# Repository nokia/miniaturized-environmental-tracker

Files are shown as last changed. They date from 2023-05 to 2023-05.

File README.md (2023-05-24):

# Introduction 

 Miniaturized Environmental Tracker is a device developed by Data and Device Group of Nokia Bell Labs at Cambridge site during 2018-2020. The device is called Gecko (originally: gatekeeper) and both names are widely used in this repository.   
 The original and main developer of the firmware is our previous colleague Philip Derrick (https://github.com/phild68).

## Devices details

Gecko is a portable environmental sensing device. It contains temperature, air pressure, air quality, light, sound and IMU sensors. The device also has a solar panel for energy harvesting. We have manufactured hardware devices in two sizes, with different dimensions and battery sizes. 
1) Gecko, the normal size device, has a size of 55x25x15 mm with 500 mAh LiPo battery and  weight of about 24 grams. 

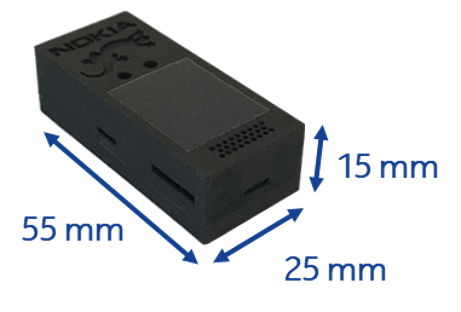
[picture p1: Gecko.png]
Gecko


2) Geckino, smaller size version, has a size of  40x25x15 mm with 150 mAh LiPo battery and weight of about 16 grams.    
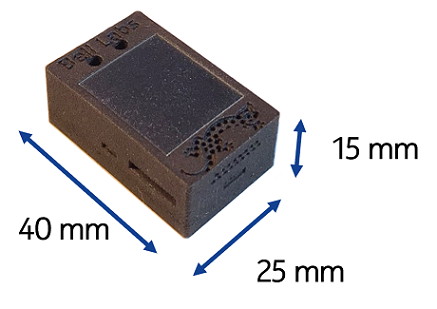
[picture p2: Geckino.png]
Geckino


### MCU and Sensors
* MCU is ARM-based Cortex M4-F 64MHz processor nRF52832 from Nordic Semiconductor.   
* Pressure and temperature sensor: LPS22HB from STMicroelectronics.  
* Gas Quality Sensor (Volatile Organic Compounds): BME680 from Bosch Sensortec. It can measure temperature, pressure and humidity as well.  
* Colour/Light Sensor: BH1745NUC from Rohm Semiconductor.  
* Digital microphone: MP34DT05 from STMicroelectronics.  
* Motion Sensor (6-axis, Accelerometer and Gyroscope): BMI160 from Bosch Sensortec.  

## Data parsing
Gecko's data can be saved on SD card or real time streamed over BLE according to application scenarios. All sensor's data saved in SD cards is in binary format with filename DLOG\_\*.BIN. The BIN file data can be procesed by python scripts for human and machine reading. 

## Firmware and programming instructions

The firmware for Gecko was developed in Segger Embedded Studio with Nordic Semiconductor nRF5 SDK 15.3.0 with softdevice version s132. 
Segger Embedded Studio can be downloaded: https://www.segger.com/products/development-tools/embedded-studio/

nRF5 SDK 15.3.0 can be downloaded: https://www.nordicsemi.com/Products/Development-software/nRF5-SDK/Download#infotabs

JLink device hardare, its drive (https://www.segger.com/downloads/jlink/) and nRF Command Line Tools are also required for compiling and uploading the firmware to device. 

## How to start 
Download and Install Segger Embedded Studio and get a license for Nordic MCU as needed. Version of SDK used is:   
* nRF5 SDK 15.3.0    

Download above nRF5 SDK 15.3.0 and unzip the whole package of nRF5_SDK_15.3.0_59ac345 in a working directory and copy gecko-fw folder in this repository into it. The Segger project file for gecko-fw can be loaded from:  
`gecko-fw/ble_peripheral/ble_app_gatekeeper/gecko/s132/ses/ble_app_gecko_s132.emProject`

### Modifications to nRF5 SDK 15.3.0 files
The following code modifications may be required for compiling in current version of Segger Embedded Studio 6.34: 
1. 	 components/libraries/uart/regart.c 

	Line 101 change: 
	`#if defined(__SES_VERSION) && (__SES_VERSION >= 34000)` to 
	`#if defined(__SES_VERSION) && (__SES_VERSION >= 34000) && !defined(__SEGGER_RTL_VERSION)`
2.   external/fatfs/src/ffconf.g

	Line 101 change to the following to enable long filename support:
	`#define	_USE_LFN	2`
3.   components/libraries/bsp/bsp_config.h

	Line 89 and 90: 
	`#define ADVERTISING_LED_ON_INTERVAL            50 //200`
	`#define ADVERTISING_LED_OFF_INTERVAL           9950 //1800`
	This is to make the LED advertising less frequently. 
4.   You may also need to change the following file: 	external/segger_rtt/SEGGER_RTT_Syscalls_SES.c

  Add `#if !defined(__SEGGER_RTL_VERSION)` at line 72 and `#endif` at around line 262.
   
If there are more errors during compiling, you may want to switch Segger Embedded Studio to early version published during 2019, for instance V5.40.
### Other compiler
The project can also be complied with armgcc. the Makefile is located at: gecko-fw/ble_peripheral/ble_app_gatekeeper/gecko/s132/armgcc 

### Hardware programming interface
First time programming of Gecko need to go through SWD interface embedded with micro-USB plug. SWD pin configuration can be found in the hardware schematic files. A customized interface connection need to be made to programmer (JLink or others). 

### Other related instructions 
 Other useful documents and related instructions:

 * gecko-fw/README.md
 * gecko-fw/ble_peripheral/ble_app_gatekeeper/DFU_README.md  
 
 ## Other files in this repository
 
 * gecko-hw  
 Gecko PCB hardware design files for production.
 
 * gecko_ble_gateway  
 Raspberry Pi gateway used to collect Gecko data over BLE in real time, parsing data and forward  data in json format to remote server. 
 
 * gecko-case  
 Case designs for both versions of the device: Gecko and Geckino.

 * data_parsing_scripts  
 For processing binary files in \*.BIN format saved on SD card to human readable format. Similar script is also used in gecko_ble_gateway files.

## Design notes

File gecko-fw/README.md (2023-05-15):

# Gecko Sensor Electronics Firmware

This project develops firmware for Gecko environmental sensor. 

This database (gecko-fw folder) should be cloned into the top level of the nRF5 SDK. The version used for development is nRF5\_SDK\_15.3.0\_59ac345. This can be obtained from the Nordic Website ([https://www.nordicsemi.com/Software-and-Tools/Software/nRF5-SDK/Download#infotabs]())

In this case, place gecko-fw folder under nRF5_SDK_15.3.0_59ac345.

All code has been developed using SES and aslo tested with armgcc. 

### To Make a DFU firmware image
1) Build the firmware in Segger Studio.  
2) go to /ble_peripheral/ble_app_gatekeeper.  
3) On a PC in command line run: "sh generateSoftDeviceAndBootloaderHex.sh".  
4) Go to Segger Studio and Upload Image to device.   

### To Make a .zip file
1) Build the firmware in Segger Studio  
2) go to /ble_peripheral/ble_app_gatekeeper  
3) On a PC in command line run: "sh make_zip_file.sh"  
4) Transfer .zip to phone and use nRF Connect 

### Use of Makefile
Makefile under the folder /ble_peripheral/ble_app_gatekeeper is fully working now. One thing need to be done is to add Segger Embedded Studio bin folder to path of the shell you are using. One Mac the following can be added to the end of .bash_prifile (or .zshrc if you are ing zsh), with your version of Segger Embedded Studio. 

```bash
# Segger Embedded Studio  
export SEGGER_VERSION=4.40  
export PATH="$PATH:/Applications/SEGGER Embedded Studio for ARM ${SEGGER_VERSION}/bin"

```

#### Then make has the follow targes to use:  

     all                                    :  Prepare hex and zip files, not including program and upload2cloud  
     micro-ecc                              :  Obtain and make the micro-ecc library. Only needs to be done once.  
     bootloader                             :  Compile secure bootloader image
     bootloader_Settings.hex                :  Generate bootloader settings for current application.  
     bootloaderWithSettings.hex             :  Combine bootloader with bootloader settings.  
     merged_SD_Bootloader.hex               :  Combine bootloader with bootloader settings and SoftDevice.  
     merged_SD_Bootloader_Application.hex   :  Combine bootloader with bootloader settings, SoftDevice, and Application.  
     app_dfu_package.zip                    :  Generate the package for DFU update
     program                                :  Program the Initial Image to nrf52 device. 
     upload2cloud                           :  Upload the initial Image to iClould on Mac computer.  
     clean                                  :  Clean volatile stuff.  
     clean-all                              :  Clean Everything including micro-ecc

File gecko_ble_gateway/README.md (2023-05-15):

# Gecko Gateway Apps

|  Directory | Gateway Version  | 
|---|---|
|  gw.python | Raspberry Pi version  |

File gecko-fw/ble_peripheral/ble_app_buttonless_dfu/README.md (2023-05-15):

# Buttonless DFU for Gecko

##Reference
[https://devzone.nordicsemi.com/nordic/nordic-blog/b/blog/posts/getting-started-with-nordics-secure-dfu-bootloader
]()

Note: The above tutorial instructs to flash the softdevice first, and then the bootloader. THIS DOES NOT WORK as the bootloader overwrited the softdevice. The correct way to do this is to use mergehex to merge the two hex files together. This is part of the nRF Command Line Tools (as is nrfjprog). 

There is also a step-by-step tutorial (which uses mergehex) based on the above at 
[https://github.com/gamnes/nRF52832-buttonless-dfu-development-tutorial]()

## Steps

Step A. Generate keys

Step B. Build the bootloader and merge with the softdevice.

Step C. Generate DFU .zip packet

Step D. Test DFU

Step E. Update new application firmware (Optional)

##Notes
Generated Keys are in dfu/gecko\_public\_key.c and dfu/gecko\_private.key in the workspace.

Bootloader is dfu/secure\_bootloader

ble\_peripheral/ble\_app\_buttonless_dfu is the current starter example. This is where the zip file is located. 

## Step A. Generate Keys
In ble\_peripheral/ble\_app\_buttonless_dfu run the following nrfjprog command to generate the private key

`nrfutil.exe keys generate private.key
`

Generate the public key based on the private key

`nrfutil keys display --key pk --format code private.key --out_file public_key.c
`

This step has already been done and the keys are included in this repository: 

		dfu/gecko_public_key.c
		dfu/gecko_private.key 

## Step B. Build the BootLoader

This needs to be rebuilt using the private key generated above. 

Scripts have been provided to do this. 

1. Install micro\_ecc in the nRF5-SDK (01\_uECC\_build.sh)
2. Build the bootloader and merge with the softdevice (02\_Bootloader\_build.sh)
3. Build the DFU image from the required application (03\_DFU\_build.sh)
4.

## Step C. Generate the DFU .zip Packet

Build the new version of the application and then build the signed package.

For an example go to ble\_peripheral/ble\_app\_buttonless\_dfu and run the 03\_DFU\_build.sh script.

## Step D. Test DFU
Program the bootloader with 04\_DFU\_Program.sh

Use over the air update to program the application. This requires nRFConnect and does not work on Linux or OSX.

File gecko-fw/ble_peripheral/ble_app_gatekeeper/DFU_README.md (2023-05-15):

# Gecko Device Firmware Update (DFU) Instruction

## Step 1 - Keys

Keys have already been generated and are in dfu/gecko\_public\_key.c and dfu/gecko\_private.key in the workspace. Replacement keys can be generated with the following commands: -

`nrfutil keys generate private.key`

`nrfutil keys display --key pk --format code private.key --out_file dfu_public_key.c`

## Step 2 - Install Micro-ECC

Go to the SDK Root directory and enter external/micro-ecc. Run build_all.sh or build_all.exe. On UNIX based systems (including OS-X) it may be necessary to run dos2unix on build_all.sh first.

## Step 3 - Build Bootloader

Bootloader is in dfu/secure\_bootloader folder. To build the bootloader go to that directory and run make. Use the argument DEBUG=1 for the debug build.

## Step 4 - Compile the Application
Compile the Application in Segger Embedded Studio using 

`gecko/s132/ses/ble\_app\_gecko\_s132.emProject`

The application hex file should be located under 

`gecko/s132/ses/Output/Debug/Exe/ble\_app\_gecko\_s132.hex`

## Step 5 - Modify Bootloader and combine images.
The bootloader then needs to be modified with the details of the Application executable. For this, the generateSoftDeviceAndBootloaderHex.sh can be used. This generates the correct bootloader settings for the Application, and merges this resultant hex with the bootloader hex, and then with the softdevice hex producing a single hex file that can be loaded by Segger Embedded Studio. It also creates the combined Application, Bootloader and Softdevice for programming with nrfjprog. 

SES calls a script from the <project>/s132/ses directory which calls the generateSoftDeviceAndBootloaderHex.sh after Linking and before Loading.

## Makefile Option
Ultimately these steps should be wrapped up in a makefile but currently this is not fully working.

## Application DFU Package
To generate the package to transmit over the DFU protocol run 

`make app_dfu_package.zip`

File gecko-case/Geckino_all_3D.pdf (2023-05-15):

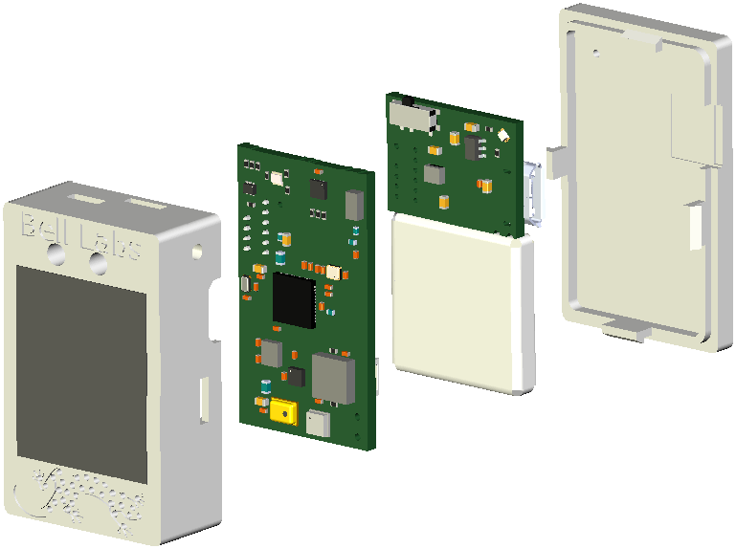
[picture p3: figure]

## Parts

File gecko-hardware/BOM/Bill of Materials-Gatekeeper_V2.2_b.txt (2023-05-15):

Designator,Name,Quantity,Description,Manufacturer 1,Manufacturer Part Number 1,Manufacturer Lifecycle 1,Supplier 1,Supplier Part Number 1,Supplier Unit Price 1,Supplier Subtotal 1
,,,,,,,,,,
AT1,2450AT18B100,1,2.45 GHz chip antenna,Johanson,2450AT18A100E,Volume Production,Arrow,2450AT18A100E,0.47459,0.47459
"C1, C12",4.7uF,2,"Capacitor, 0603, X5R, ±10% ",KEMET,C0603C475K9PACTU,Volume Production,Digi-Key,399-3482-6-ND,0.13424,0.26849
C2,10nF,1,"Capacitor, 0402, X7R, ±5%",Yageo,CC0402JRX7R9BB103,Volume Production,Arrow,CC0402JRX7R9BB103,0.07502,0.07502
C3,47uF,1,"Chip Capacitor, 47 uF, +/- 20%, 10 V, -55 to 85 degC, 0805 (2012 Metric), RoHS, Tape and Reel",TDK,C2012X5R1A476M125AC,Volume Production,Mouser,810-C2012X5R1A476M,0.83705,0.83705
"C4, C11, C13, C17, C24, C25, C26, C27, C28, C29, C30, C32, C35, C37",100nF,14,"Capacitor, 0402, X7R, ±10%",Wurth Electronics,885012205037,Volume Production,Mouser,710-885012205037,0.01579,0.22111
"C5, C6, C14, C31",1.0uF,4,"Capacitor, 0603, X7R, ±10% ",Taiyo Yuden,JMK107B7105KA-T,Volume Production,Mouser,963-JMK107B7105KA-T,0.07897,0.31587
"C7, C36",10uF,2,"Capacitor, 0603, X5R, ±10%",TDK,C1608X5R1A106K080AC,Volume Production,Future Electronics,C1608X5R1A106K080AC-CUTT,0.14846,0.29692
C8,22uF,1,"Capacitor, 0603, X5R, ±20%",TDK,C1608X5R1A226M080AC,Volume Production,Future Electronics,C1608X5R1A226M080AC-CUTT,0.12793,0.12793
"C9, C10, C15, C16, C19, C20",12pF,6,"Capacitor, 0402, NP0, ±2%",Murata,GJM1555C1H120GB01D,Volume Production,Digi-Key,490-8078-6-ND,0.21321,1.28
C18,0.8pF,1,"Capacitor, NP0, ±5%",Murata,GJM1555C1HR80WB01D,Volume Production,Arrow,GJM1555C1HR80WB01D,0.22498,0.22498
C21,100pF,1,"Capacitor, 0402, NP0, ±5%",Murata,GRM0225C1E101JA02L,Volume Production,Arrow,GRM0225C1E101JA02L,0.07502,0.07502
C23,2.2pF,1,"Capacitor, 0402, NP0, ±0.1pF",Murata,GJM1555C1H2R2BB01D,Volume Production,Arrow,GJM1555C1H2R2BB01D,0.12753,0.12753
"C33, C34",270pF,2,"Capacitor, 0402, NP0, ±2%",KEMET,C0402C271G5GACTU,Volume Production,Mouser,80-C0402C271G5G,0.82126,1.64
FB1,600R/0.5A,1,"Ferrite Bead, 0603, 600 Ohm @ 100MHz, 500mA, 380 mOhm Max",Murata,BLM18AG601SN1D,Volume Production,Future Electronics,BLM18AG601SN1D-CUTT,0.02993,0.02993
J1,FPC 0.5mm RA SMD,1,"0.5mm FPC, 5P,Right Angle SMT,Double Contact,H=1.2mm,White, Tin plated",Molex,51281-0594,Volume Production,Arrow,51281-0594,0.33924,0.33924
L1,LPS4018-223MRB,1,"Shielded Power Inductor, 22 uH, +/- 20%, 360 mOhm, -40 to 85 degC, 2-Pin SMD, RoHS, Tape and Reel",Coilcraft,LPS4018-223MRB,Volume Production,Mouser,994-LPS4018-223MRB,0.90023,0.90023
L2,15nH,1,"Inductor, 0402, 320mA, ±5%",Taiyo Yuden,HK100515NJ-T,Volume Production,Future Electronics,HK100515NJ-T-CUTT,0.01571,0.01571
L3,10uH,1,"Inductor, 0603, 80mA, ±10%",Taiyo Yuden,LBMF1608T100K,Volume Production,,,,
"L4, L6",3.9nH,2,"Inductor, 170mA, ±0.1nH",Murata,LQP15MN3N9B02D,Volume Production,Digi-Key,490-1131-6-ND,0.15004,0.30008
LED1,Red,1,"SMD mono-color Chip LED, WL-SMCW, Red",Wurth Electronics,150060RS75000,Volume Production,Digi-Key,732-4978-1-ND,0.11055,0.11055
LED2,LED RGB,1,RGB LED 1.60 mm x 1.60 mm SMD,Vishay Lite-On,LTST-C19HE1WT,Volume Production,Future Electronics,LTST-C19HE1WT-CUTT,0.17373,0.17373
P3,MicroUSB-B,1,MicroUSB-B-SMT,Amphenol FCI,10118193-0001LF,Volume Production,Allied Electronics,70236827,0.26849,0.26849
Q1,DMC2400UV,1,"Dual N & P Ch MOFET, 1.03A/0.7A, 480mOhm, 450mW",Diodes,DMC2400UV-7,Volume Production,Digi-Key,DMC2400UV-7DIDKR-ND,0.39484,0.39484
"R1, R9",4.42M,2,"Resistor, 0402, ±1%, 0.063W",Yageo,RC0402FR-074M42L,Volume Production,Mouser,603-RC0402FR-074M42L,0.00948,0.09476
R2,10M,1,"Resistor, 0402, ±1%, 0.063W",Yageo,RC0402FR-0710ML,Volume Production,Future Electronics,RC0402FR-0710ML-CUTT,0.00229,0.00229
"R2b, R8",5.62M,2,"Resistor, 0402, ±1%, 0.063W",Yageo,RC0402FR-075M62L,Volume Production,Mouser,603-RC0402FR-075M62L,0.00948,0.09476
R3,4.32k,1,"Resistor, 0402, ±1%, 0.063W",Vishay,CRCW04024K32FKED,Volume Production,Farnell,1151240,0.0114,0.0114
R4,470R,1,"Resistor, ±1%, 0.063W",Vishay,CRCW0402470RFKED,Volume Production,Digi-Key,541-470LDKR-ND,0.07897,0.07897
R5,XH10k,1,THERMISTOR 10K OHM NTC 0402 SMD,Murata,NCP15XH103F03RC,Volume Production,Future Electronics,NCP15XH103F03RC-CUTT,0.06594,0.06594
"R6, R11",6.04M,2,"Resistor, 0402, ±1%, 0.063W",Yageo,RC0402FR-076M04L,Volume Production,Mouser,603-RC0402FR-076M04L,0.00948,0.09476
R7,3.83M,1,"Resistor, 0402, ±1%, 0.063W",Panasonic,ERJ-2RKF3831X,Volume Production,Arrow,ERJ-2RKF3831X,0.07502,0.07502
R10,3.32M,1,"Resistor, 0402, ±1%, 0.063W",Yageo,RC0402FR-073M32L,Volume Production,Arrow,RC0402FR-073M32L,0.07502,0.07502
R12,536k,1,"Resistor, 0402, ±1%, 0.063W",Panasonic,ERJ-2RKF5360X,Volume Production,Arrow,ERJ-2RKF5360X,0.00411,0.00411
"R15, R22, R26, R27",10k,4,"Resistor, 0402, ±1%, 0.063W",Panasonic,ERJ2RKF1002X,Volume Production,Allied Electronics,70265404,0.00948,0.0379
R16,100R,1,"Resistor, 0402, ±1%, 0.063W",Vishay Dale,CRCW0402100RFKED,Volume Production,Future Electronics,CRCW0402100RFKED-CUTT,0.0064,0.0064
"R17, R18",39R,2,"Resistor, 0402, ±1%, 0.063W",Vishay,CRCW040239R0FKED,Volume Production,Future Electronics,CRCW040239R0FKED-CUTT,0.00576,0.01153
"R19, R24, R25",4k7,3,"Resistor, 0402, ±1%, 0.063W",Vishay,CRCW04024K70FKED,Volume Production,Future Electronics,CRCW04024K70FKED-CUTT,0.0135,0.04051
"R20, R21",1M0,2,"Resistor, ±1%, 0.063W",Vishay,CRCW04021M00FKED,Volume Production,Future Electronics,CRCW04021M00FKED-CUTT,0.00268,0.00537
R23,21k5,1,"Resistor, ±1%, 0.063W",Vishay,CRCW040221K5FKED,Volume Production,Mouser,71-CRCW0402-21.5K-E3,0.07897,0.07897
SD1,DM3D-SF,1,"Micro SD Card Connector, Push-Pull, Top Board Mounting, 125 V, 0.5 A, -25 to 85 degC, 8-Pin SMD, RoHS, Tape and Reel",Hirose,DM3D-SF,Volume Production,Future Electronics,DM3D-SF-CUTT,1,1
SW1,PCM12SMTR,1,"Ultraminiature Slide Switch, SPDT, 0.3 A, 6 V, -20 to 85 degC, 3-Pin SMD, RoHS, Tape and Reel",ITT C&K,PCM12SMTR,Volume Production,Allied Electronics,70417448,0.46433,0.46433
SW2,USLPT3026BL1TR,1,"Low-Profile Tactile Switch, SPST, 50 mA, 12 VDC, -40 to 85 degC, 4-Pin SMD, RoHS, Tape and Reel",TE Connectivity,USLPT3026BL1TR,,Farnell,2990969,0.475,2.38
U1,BQ25504RGTT,1,"Ultra Low Power Boost Converter with Battery Management for Energy Harvester App, 0.13 V, -40 to 85 degC, 16-pin QFN (RGT), Green (RoHS & no Sb/Br)",Texas Instruments,BQ25504RGTT,Volume Production,Newark,76T8906,1.93,1.93
U2,BQ21040DBVR,1,0.8A Single Input Single-Cell Li-Ion and Li-Pol Battery Charger,Texas Instruments,BQ21040DBVR,,Mouser,595-BQ21040DBVR,0.86864,0.86864
U3,XCL210C33,1,3.3V 200mA Inductor Built-in Step-Down “micro DC/DC” Converter,Torex,XCL210C331GR-G,Volume Production,Digi-Key,893-1255-6-ND,2.2,2.2
U4,nRF52832-QFAAB0,1,"Multi-protocol Bluetooth Low Energy, ANT and 2.4GHz proprietary system-on-chip",Nordic Semiconductor,NRF52832-QFAA-R,Volume Production,Arrow,NRF52832-QFAA-R,4.24,4.24
U5,BMI160,1,"BMI160, IMUs - Inertial Measurement Units 6-Axis 950uA",Bosch,BMI160,,Future Electronics,BMI160-CUTT,3.5,3.5
U6,SST26VF032-80-5I-S2AE,1,"32 Mbit Serial Quad I/O (SQI) Flash Memory, 2.7 to 3.6 V, 80 MHz, -40 to 85 degC, 8-pin SOIC (S2A8), Tube",Microchip,SST26VF032-80-5I-S2AE,Volume Production,Arrow,SST26VF032-80-5I-S2AE,2.16,2.16
U7,LPS22HB,1,MEMS nano pressure sensor: 260-1260 hPa absolute digital output barometer,STMicroelectronics,LPS22HBTR,Volume Production,Arrow,LPS22HBTR,1.94,1.94
U8,BME680,1,"Combined Humidity and Pressure Sensor, 1.71 to 3.6 V, -40 to 85 degC, 8-Pin SMD, RoHS, Tape and Reel",Bosch Sensortec,BME680,,Arrow,BME680,9.96,9.96
U9,MP34DT05,1,MEMS audio sensor omnidirectional digital microphone,STMicroelectronics,MP34DT05TR-A,,Future Electronics,MP34DT05TR-A-CUTT,0.75019,0.75019
U10,BH1745NUC,1,Digital 16bit Serial Output Type Color Sensor IC,Rohm,BH1745NUC-E2,Volume Production,Farnell,2663354,1.2,1.2
U11,NX3DV2567,1,Low-ohmic four-pole double-throw analog switch,NXP Semiconductors,"NX3DV2567GU,115",Volume Production,Arrow,"NX3DV2567GU,115",0.437,0.437
X1,32.768kHz,1,"XTAL SMD 2012, 32.768kHz, 9pF, ±20ppm",Abracon,ABS06-32.768KHZ-9-1-T,Volume Production,Future Electronics,ABS06-32.768KHZ-9-1-T-CUTT,0.42247,0.42247
X2,32MHz,1,"XTAL SMD 2016, 32MHz, Cl=8pF, Tot: ±40ppm",Kyocera AVX,CX2016DB32000D0WZRC1,Volume Production,Arrow,CX2016DB32000D0WZRC1,0.55948,0.55948

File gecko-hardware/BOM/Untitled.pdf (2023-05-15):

PatchKeeper_V1.0

Designator | Comment | Quantity | Footprint | Description
C1, C2 | GJM1555C1H120GB01D | 2 | CAPC0402(1005)60_L | Multilayer Ceramic Capacitors MLCC - SMD/SMT 0402 12pF 50Volts C0G 2%
C13, C14 | CAP 1uF 16V 0402(1005) | 2 | CAPC0402(1005)60_L | CAP 1uF 16V ±10% 0402 (1005 Metric) Thickness 0.6mm SMD
C15, C17 | GRM155R71E473KA88D | 2 | CAPC0402(1005)60_L | Chip Capacitor, 47 nF, +/- 10%, 25 V, -55 to 125 degC, 0402 (1005 Metric), RoHS, Tape and Reel
C16 | 10 uF | 1 | CAPC0603(1608)100_L | Capacitor, 0603, X7R, ±10%
C19 | 1.5nF 25V 0402(1005) | 1 | CAPC0402(1005)60_L | CAP 1.5nF 25V ±5% 0402 (1005 Metric) Thickness 0.6mm SMD
C20, C21 | GRM1557U1A302JA01D | 2 | CAPC0402(1005)60_L | 0402, 3000 pF, 10V, U2J, 5%, -55C - 125 C
C22, C23, C24, C25 | GRM155R71H222KA01D | 4 | CAPC0402(1005)60_L | Chip Capacitor, 2.2 nF, +/- 10%, 50 V, -55 to 125 degC, 0402 (1005 Metric), RoHS, Tape and Reel
C3 | 4.7uF | 1 | CAPC1608X06L | CAP 4.7uF 10V ±20% 0603 (1608 Metric) Thickness 0.55mm SMD
C34, C39, C44, C49 | CAP 100nF 16V 0603(1608) | 4 | CAPC0603(1608)100_L | CAP 100nF 16V ±5% 0603 (1608 Metric) Thickness 1mm SMD
C35, C40, C45, C50 | CAP 510pF 50V 0603(1608) | 4 | CAPC0603(1608)100_L | CAP 510pF 50V ±5% 0603 (1608 Metric) Thickness 1mm SMD
C4 | 10 uF | 1 | CAPC1608X06L | Capacitor, 0603, X7R, ±10%
C5, C10, C12, C18, C26, C27, C28, C29, C30, C32, C33, C37, C38, C42, C43, C47, C48 | CAP 100nF 16V 0402(1005) | 17 | CAPC0402(1005)60_L | CAP 100nF 16V ±10% 0402 (1005 Metric) Thickness 0.6mm SMD, CAP 100nF 16V ±20% 0402 (1005 Metric) Thickness 0.6mm SMD
C6 | CAP 4.7uF 10V 0603(1608) | 1 | CAPC1608X06L | CAP 4.7uF 10V ±20% 0603 (1608 Metric) Thickness 0.55mm SMD
C7 | CAP 4.7uF 16V 0805(2012) | 1 | CAPC0805(2012)155_L | CAP 4.7uF 16V ±10% 0805 (2012 Metric) Thickness 1.55mm SMD
C8 | CAP 10uF 16V 1206(3216) | 1 | CAPC1206(3216)130_L | CAP 10uF 16V ±20% 1206 (3216 Metric) Thickness 1.3mm SMD
C9, C11, C31, C36, C41, C46, C51 | CAP 1uF 25V 0603(1608) | 7 | CAPC0603(1608)100_L | CAP 1uF 25V ±10% 0603 (1608 Metric) Thickness 1mm SMD
FB1 | 600R/0.5A | 1 | INDC1608X06L | Ferrite Bead, 0603, 600 Ohm @ 100MHz, 500mA, 380 mOhm Max
JUM | N. M. | 1 | JUMPER 0603 CON | Jumper with one side connected, the other side can be connected with 0603 0 ohm.
L1 | DFE252012F-100M=P2 | 1 | INDC2520X120N | Fixed Inductors 10uH 480mOhms 1.4A 2.5x2.0mm 20%
LED | APT1608SRCPRV | 1 | LED_0603 | LED Super Bright Red, 75 mW, 5 V, -40 to 85 degC, 2-Pin SMD, RoHS, Tape and Reel
P2 | Pin List 1x2 | 1 | LIST_1X2-NC_SMALL | Pin List 1x2, 2.54mm (100mil)
Q1 | DMC2400UV | 1 | SOTFL50P162X60-6N | Dual N & P Ch MOFET, 1.03A/0.7A, 480mOhm, 450mW
R1 | 470R 1% 0603(1608) | 1 | RESC0603(1608)_L | 470R 0.1W 1% 0603 (1608 Metric) SMD
R10 | ERJ-2GE0R00X | 1 | RESC1005X40X25LL05T05 | Chip Resistor, 0 Ohm, +/- 5%, 100 mW, -55 to 155 degC, 0402 (1005 Metric), RoHS, Tape and Reel
R11 | 1M 1% 0402(1005) | 1 | RESC1005X40X25LL05T05 | 1M 0.063W 1% 0402 (1005 Metric) SMD
R13, R14 | 40K2 1% 0402(1005) | 2 | RESC1005X40X25LL05T05 | 40K2 0.063W 1% 0402 (1005 Metric) SMD
R15, R16 | 51K 5% 0402(1005) | 2 | RESC1005X40X25LL05T05 | 51K 0.063W 5% 0402 (1005 Metric) SMD
R17, R18, R19, R20 | 10M 1% 0402(1005) | 4 | RESC1005X40X25LL05T05 | 10M 0.063W 1% 0402 (1005 Metric) SMD
R2 | RMCF0603FT10K0 | 1 | RESC0603(1608)_L | Chip Resistor, 10 KOhm, +/- 1%, 0.1 W, -55 to 155 degC, 0603 (1608 Metric), RoHS, Tape and Reel
R21 | 100R 1% 0402(1005) | 1 | RESC0402(1005)_L | 100R 0.063W 1% 0402 (1005 Metric) SMD
R22, R23 | 39R2 1% 0402(1005) | 2 | RESC0402(1005)_L | 39R2 0.063W 1% 0402 (1005 Metric) SMD
R24, R31, R37, R44 | 1K 1% 0603(1608) | 4 | RESC0603(1608)_L | 1K 0.1W 1% 0603 (1608 Metric) SMD
R25 | 2K74 1% 0603(1608) | 1 | RESC0603(1608)_L | 2K74 0.1W 1% 0603 (1608 Metric) SMD
R26, R27 | 27K4 1% 0603(1608) | 2 | RESC0603(1608)_L | 27K4 0.1W 1% 0603 (1608 Metric) SMD
R28 | 80K6 1% 0603(1608) | 1 | RESC0603(1608)_L | 80K6 0.1W 1% 0603 (1608 Metric) SMD
R29 | 200K, 1% 0603 | 1 | RESC0603(1608)_L | 200K 0.1W 1% 0603 (1608 Metric) SMD
R3, R4 | 1M 1% 0402(1005) | 2 | RESC0402(1005)_L | 1M 0.063W 1% 0402 (1005 Metric) SMD
R30, R36, R43, R50 | 100R 1% 0603(1608) | 4 | RESC0603(1608)_L | 100R 0.1W 1% 0603 (1608 Metric) SMD
R32, R33, R34, R35, R41, R42, R48, R49 | 200K 1% 0603(1608) | 8 | RESC0603(1608)_L | 200K 0.1W 1% 0603 (1608 Metric) SMD
R38, R45 | 1K02 1% 0603(1608) | 2 | RESC0603(1608)_L | 1K02 0.1W 1% 0603 (1608 Metric) SMD
R39, R40, R46, R47 | 10K 1% 0603(1608) | 4 | RESC0603(1608)_L | 10K 0.1W 1% 0603 (1608 Metric) SMD
R5, R51 | 10K 1% 0402(1005) | 2 | RESC0402(1005)_L | 10K 0.063W 1% 0402 (1005 Metric) SMD
R6 | 21K5 1% 0402(1005) | 1 | RESC0402(1005)_L | 21K5 0.063W 1% 0402 (1005 Metric) SMD
R7, R8 | 10K 1% 0402(1005) | 2 | RESC1005X40X25LL05T05 | 10K 0.063W 1% 0402 (1005 Metric) SMD
R9, R12 | 100K 1% 0402(1005) | 2 | RESC1005X40X25LL05T05 | 100K 0.063W 1% 0402 (1005 Metric) SMD
RGB | LED RGB | 1 | LED_RGB_0606 | RGB LED 1.60 mm x 1.60 mm SMD
RST | =Value | 1 | TP_SMD_Ø1.2MM | SMD testpad of various size
SD | DM3AT-SF-PEJM5 | 1 | DM3AT-SF-PEJM5 | Connector
SW1 | | 1 | SWITCH_091029001 | SPDT slide Switch, TH
T2 | Pin List 1x2 | 1 | LIST_1X2-1.27 | Pin List 1x2, 2.54mm (100mil)
TR1 | TC42X-2-204E | 1 | TC42X2103E | Trimmer Resistors - SMD 200K 2mm SMD Single Turn
U1 | BT840 | 1 | XCVR_BT840 | Bluetooth LE Module, Nordic nRF52840 SoC, Range 180 meters
U2 | MCP73831T-2ACI/OT | 1 | SOT-23-OT5_L | Miniature Single-Cell, Fully Integrated Li-Ion, Li-Polymer Charge Management Controller, 4.2V, 5-Pin SOT-23, Industrial Temperature, Tape and Reel
U3 | LM3670MF-3.3/NOPB | 1 | DBV0005A_N | Miniature Step-Down DC-DC Converter for Ultra Low Voltage Circuits, 5-pin SOT-23, Pb-Free
U4 | ADS1292RIPBS | 1 | TI-PBS32_L | 2-Channel, 24-Bit ADC with Integrated Respiration Impedance and ECG Front End, -40 to 85 degC, 32-pin QFP (PBS32), Green (RoHS & no Sb/Br)
U5 | BMI160 | 1 | BMI160-LGA14 | BMI160
U6 | MP34DB02 | 1 | RHLGA-4 (3X4X1MM) | MEMS audio sensor omnidirectional digital microphone
U7, U8, U9, U10 | INA338AIDGSTG4 | 4 | TI-DGS10_L | Wide-Temperature, Precision Instrumentation Amplifier with Shutdown, -40 to 125 degC, 10-pin SOP (DGS10), Green (RoHS & no Sb/Br)
USB | MicroUSB-B | 1 | USB-MICRO-B-RA-SMD-PIP | MicroUSB-B-SMT
VR1, VR2, VR3, VR4 | LM4050AEM3-2.0 | 4 | DBZ0003A_L | Precision Micropower Shunt Voltage Reference, 3-pin SOT-23
X1 | 32.768kHz | 1 | XTAL_2012 | XTAL SMD 2012, 32.768kHz, 9pF, ±20ppm

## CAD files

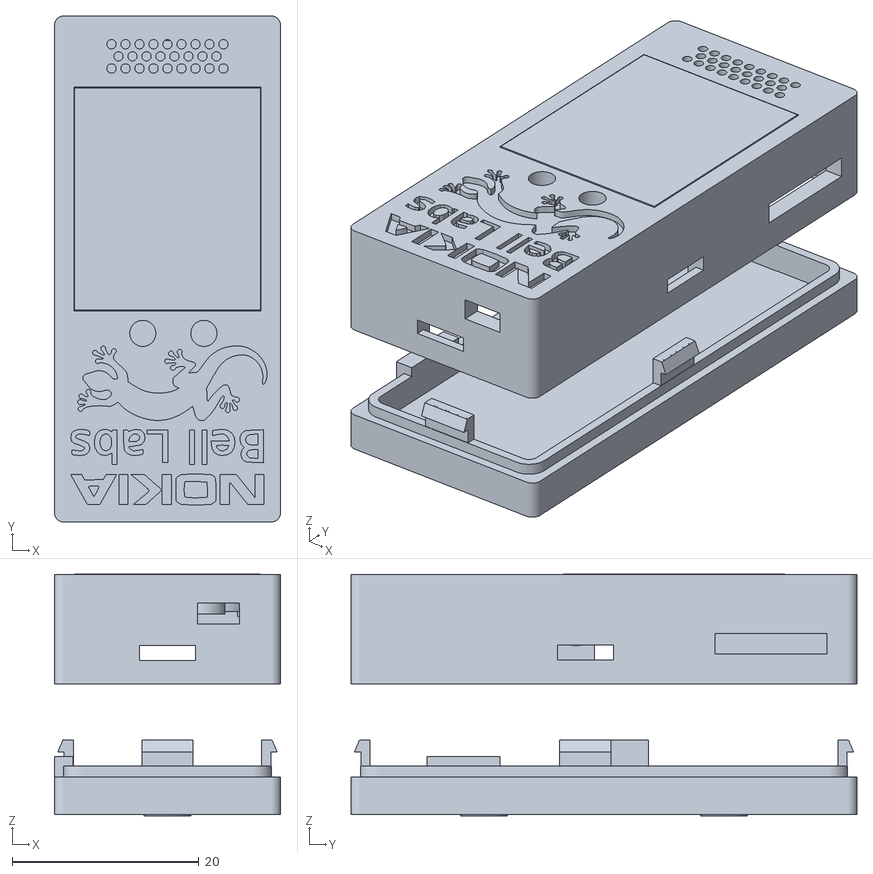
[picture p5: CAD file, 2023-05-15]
gecko-case/Gecko_V2.2_NokiaBellLabsGeckoLogo_2022.stl
24.3 x 54.3 x 25.9

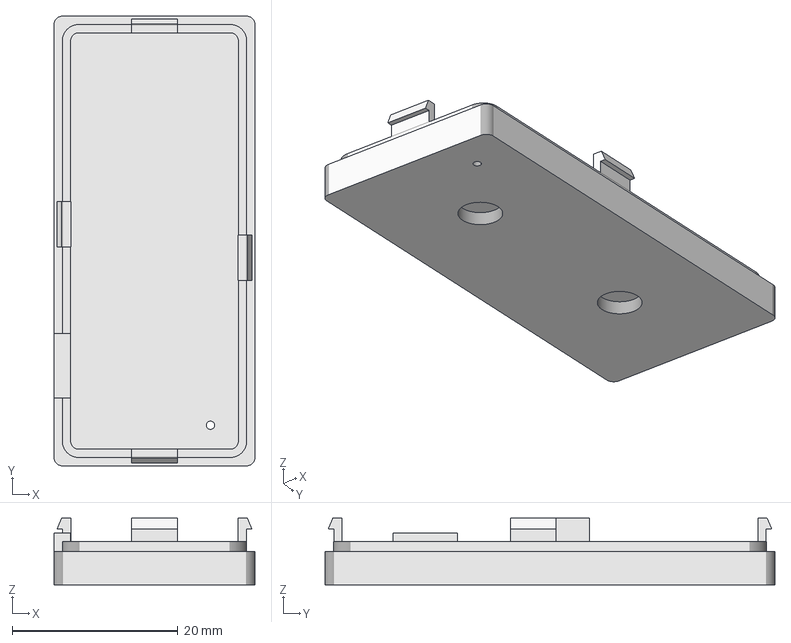
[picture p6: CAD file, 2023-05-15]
gecko-case/Gecko_V2.2_NokiaBellLabsGeckoLogo_back_FusionMaterial.step
24.3 x 54.2 x 8.04 mm

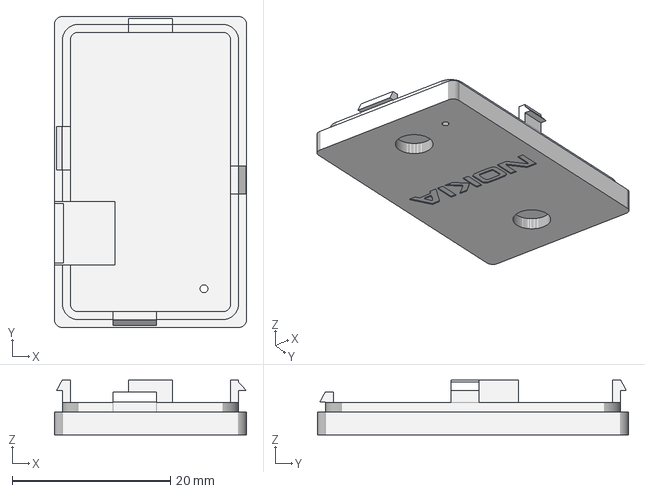
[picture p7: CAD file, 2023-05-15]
gecko-case/Geckino_case_back.step
24.2 x 39.2 x 6.94 mm

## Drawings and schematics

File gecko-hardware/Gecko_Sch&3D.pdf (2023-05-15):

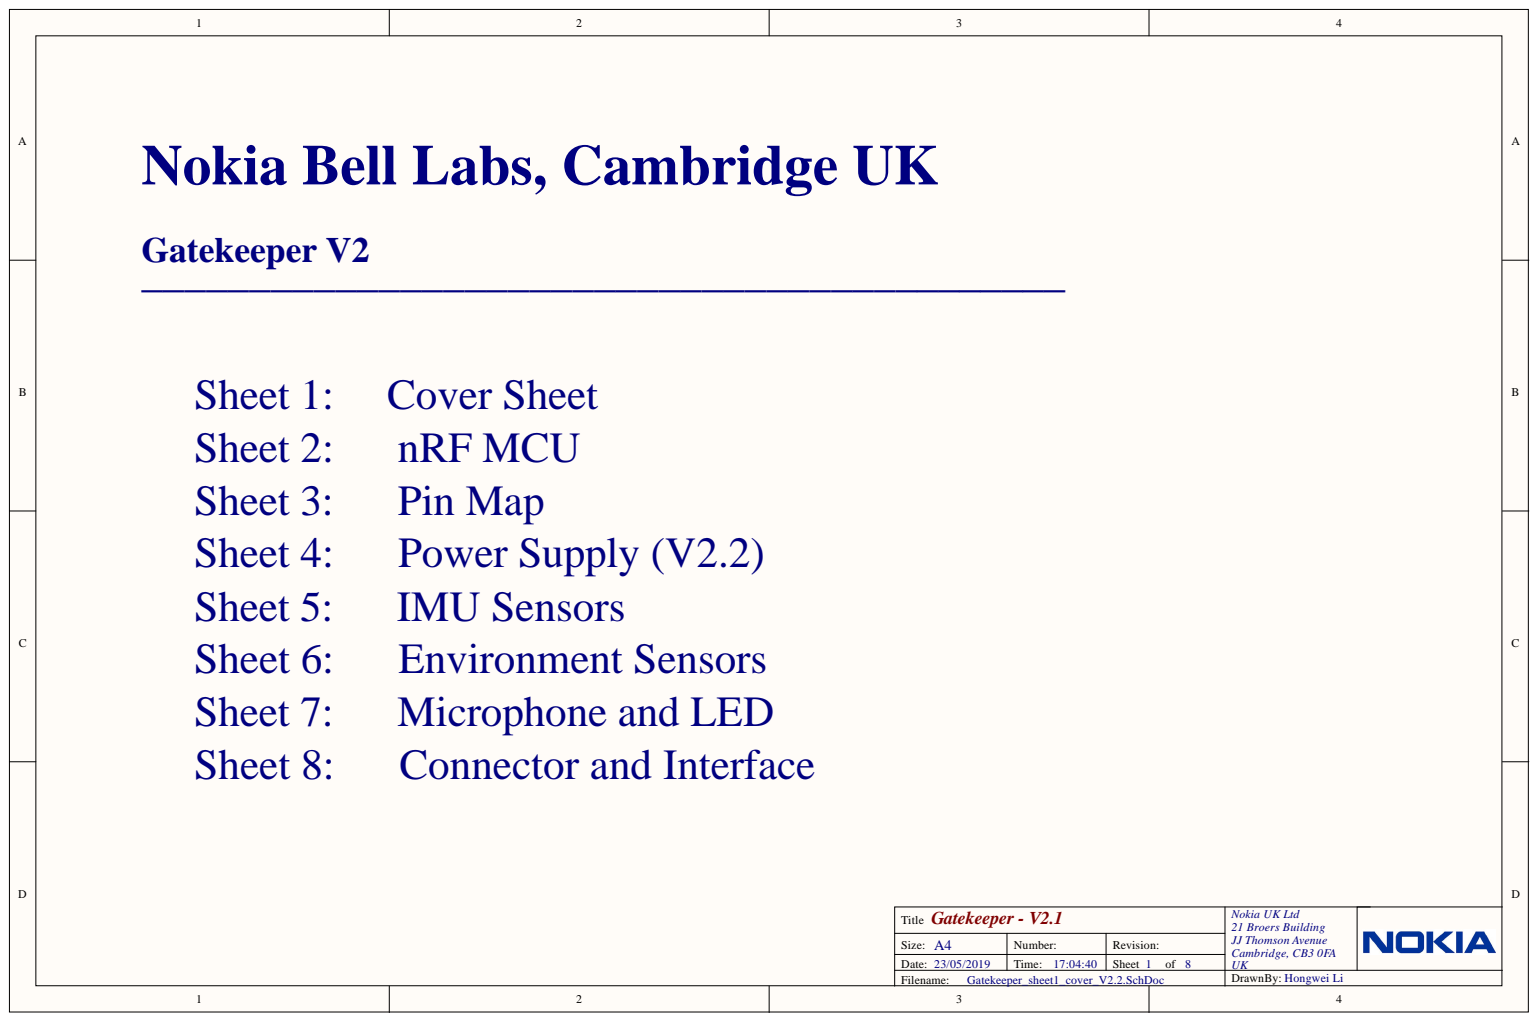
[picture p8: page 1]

Nokia Bell Labs, Cambridge UK

Gatekeeper - V2.1 Title | Nokia UK Ltd 21 Broers Building JJ Thomson Avenue UK

Size: A4 | Number: | Revision:
Date: 23/05/2019 | Time: 17:04:40 | Sheet of | Cambridge, CB3 0FA 8

Filename: Gatekeeper_sheet1_cover_V2.2.SchDoc | DrawnBy: Hongwei Li

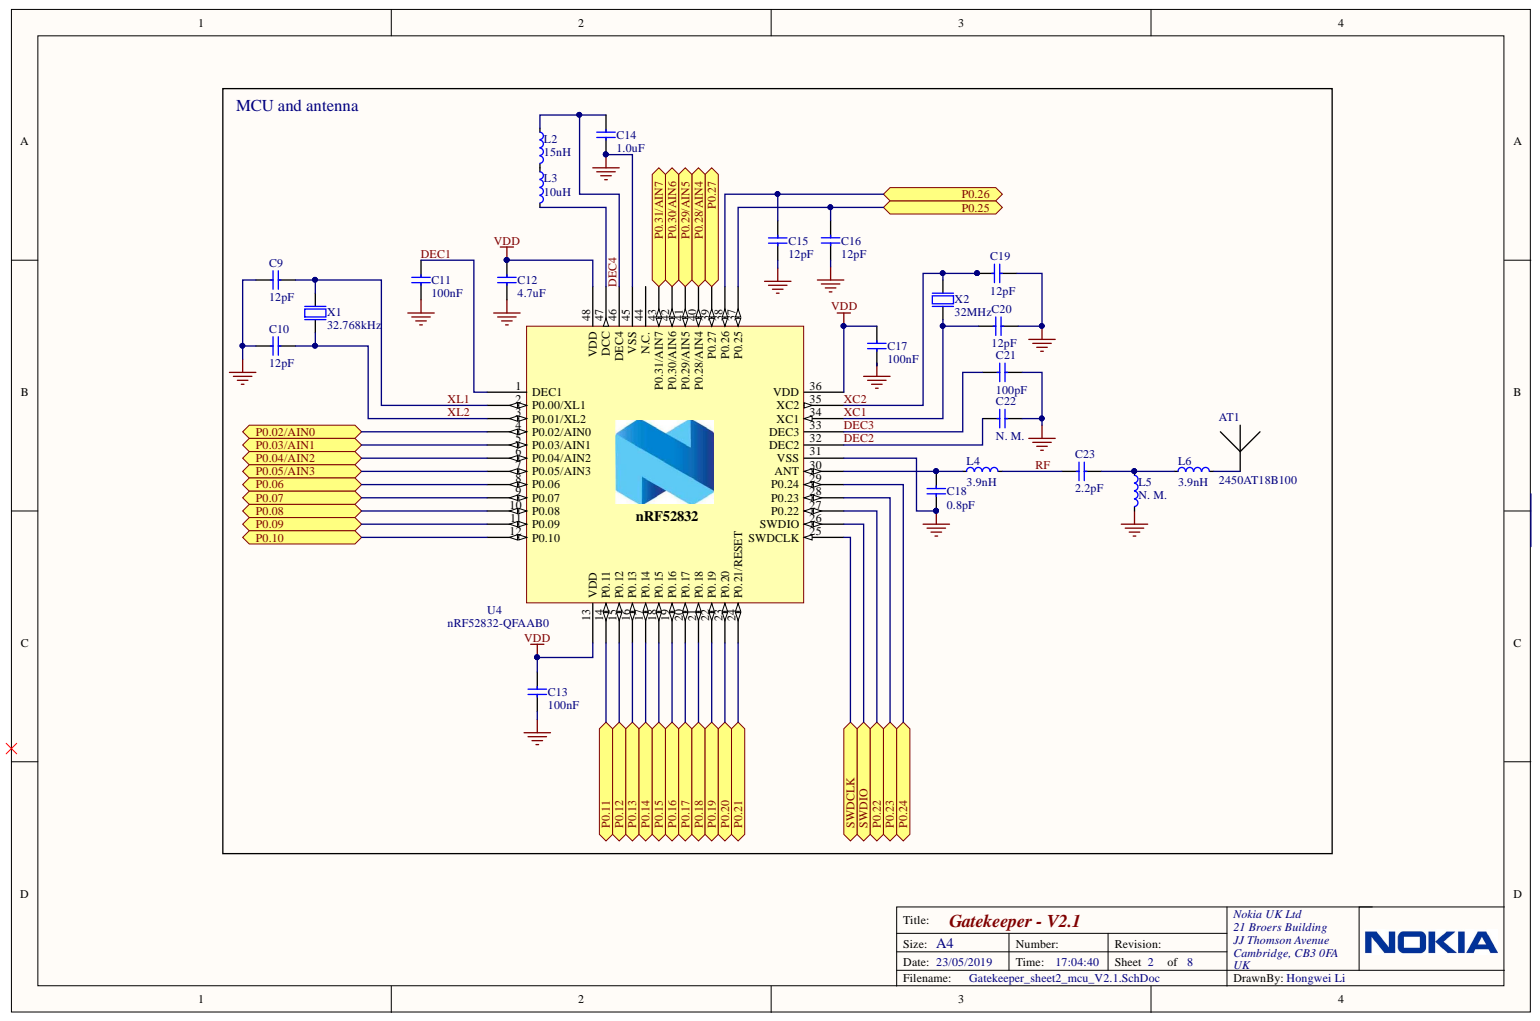
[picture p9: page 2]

MCU and antenna

12pF 32MHz C20

VDD

P0.02/AIN0 4 P0.03/AIN1 5 P0.04/AIN2 6 P0.05/AIN3 7 P0.06 8 P0.07 9 P0.08 10 P0.09 11 P0.10 12 | DEC3

DEC2

Gatekeeper - V2.1 Title: | Nokia UK Ltd 21 Broers Building JJ Thomson Avenue UK

Size: A4 | Number: | Revision:
Date: 23/05/2019 | Time: 17:04:40 | Sheet 2 of | Cambridge, CB3 0FA 8

Gatekeeper_sheet2_mcu_V2.1.SchDoc

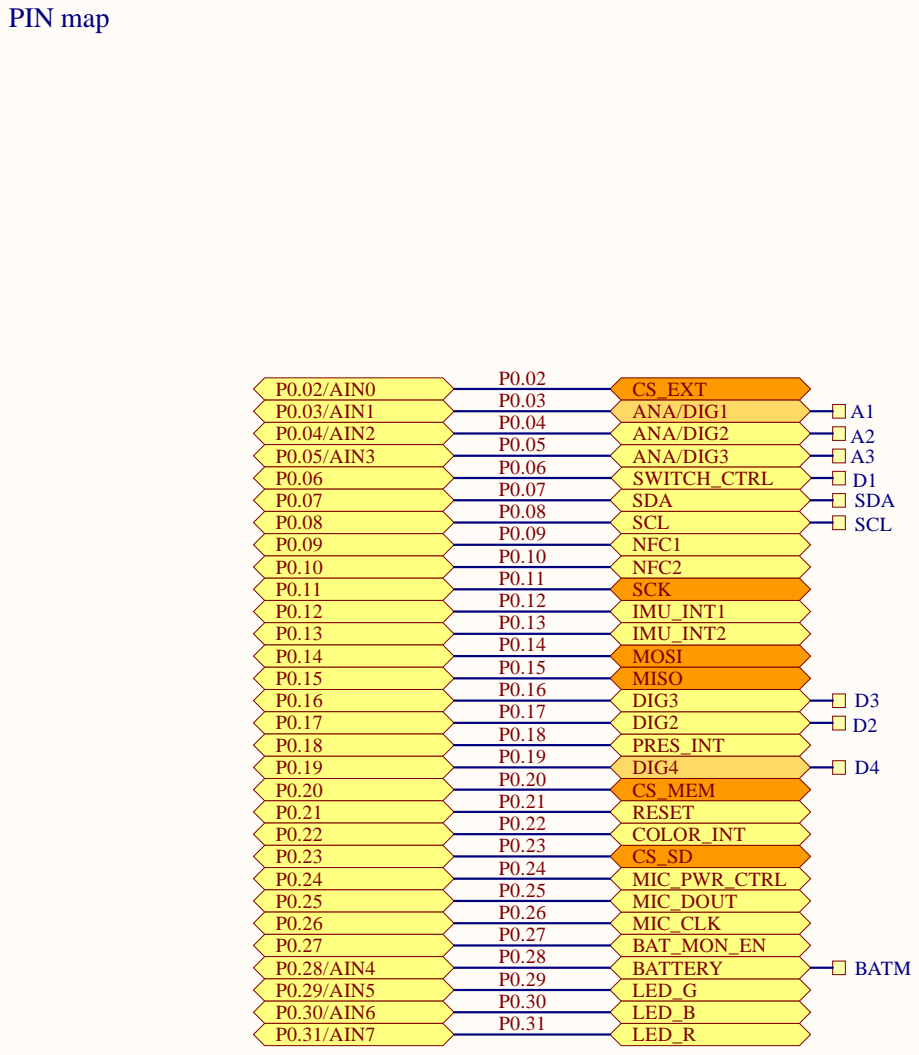
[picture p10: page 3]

Gatekeeper - V2.1 T i t le: | Noki a UK Lt d 2 1 B roer s B u i l d i n g JJ Th o m s o n Aven u e Ca m b r i dge, CB 3 0 FA UK

Size: A4 | N umber: | Rev i s i o n :
Date: 2 3 / 0 5 / 2 0 1 9 | T ime: 1 7 : 0 4 : 4 0 | Sheet 3 o f 8
Fi lename: Gatekeeper_ s heet _ p i n _map _ V 2.1.Sch D o c | Draw nBy : H o n g wei L i

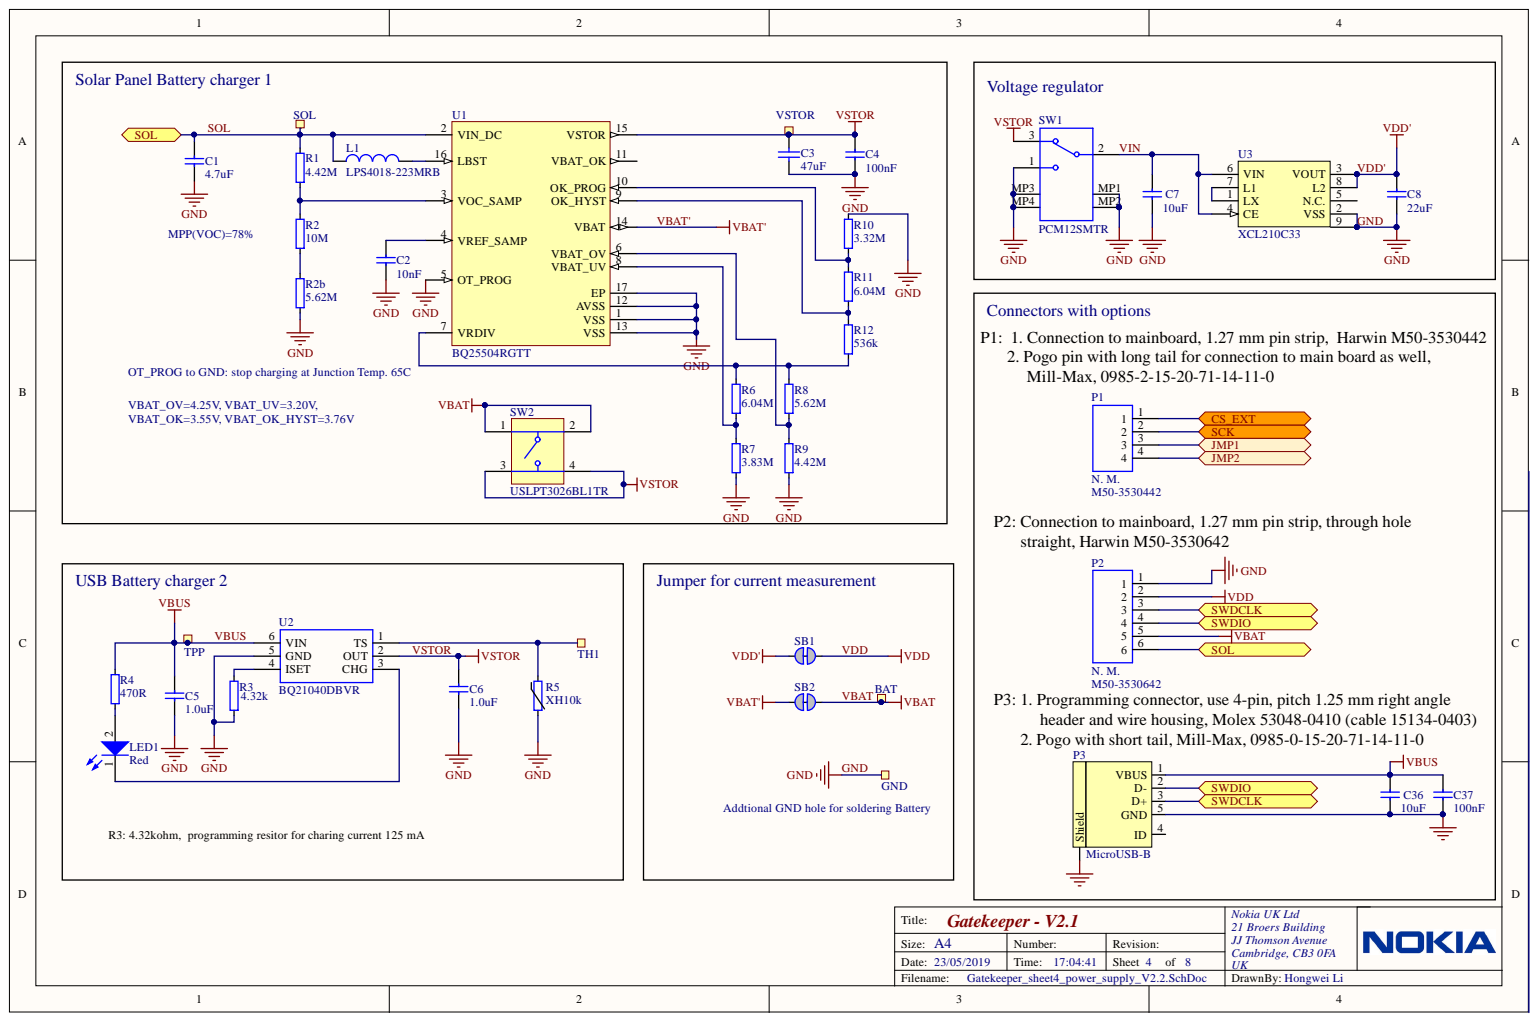
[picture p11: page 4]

GND

Connectors with options
P1: 1. Connection to mainboard, 1.27 mm pin strip, Harwin M50-3530442
2. Pogo pin with long tail for connection to main board as well,
Mill-Max, 0985-2-15-20-71-14-11-0

OT_PROG to GND: stop charging at Junction Temp. 65C

P2: Connection to mainboard, 1.27 mm pin strip, through hole
straight, Harwin M50-3530642

Jumper for current measurement

P3: 1. Programming connector, use 4-pin, pitch 1.25 mm right angle
header and wire housing, Molex 53048-0410 (cable 15134-0403)
2. Pogo with short tail, Mill-Max, 0985-0-15-20-71-14-11-0

Addtional GND hole for soldering Battery

R3: 4.32kohm, programming resitor for charing current 125 mA

Gatekeeper - V2.1 Title: | Nokia UK Ltd 21 Broers Building JJ Thomson Avenue UK

Size: A4 | Number: | Revision:
Date: 23/05/2019 | Time: 17:04:41 | Sheet 4 of | Cambridge, CB3 0FA 8

Gatekeeper_sheet4_power_supply_V2.2.SchDoc

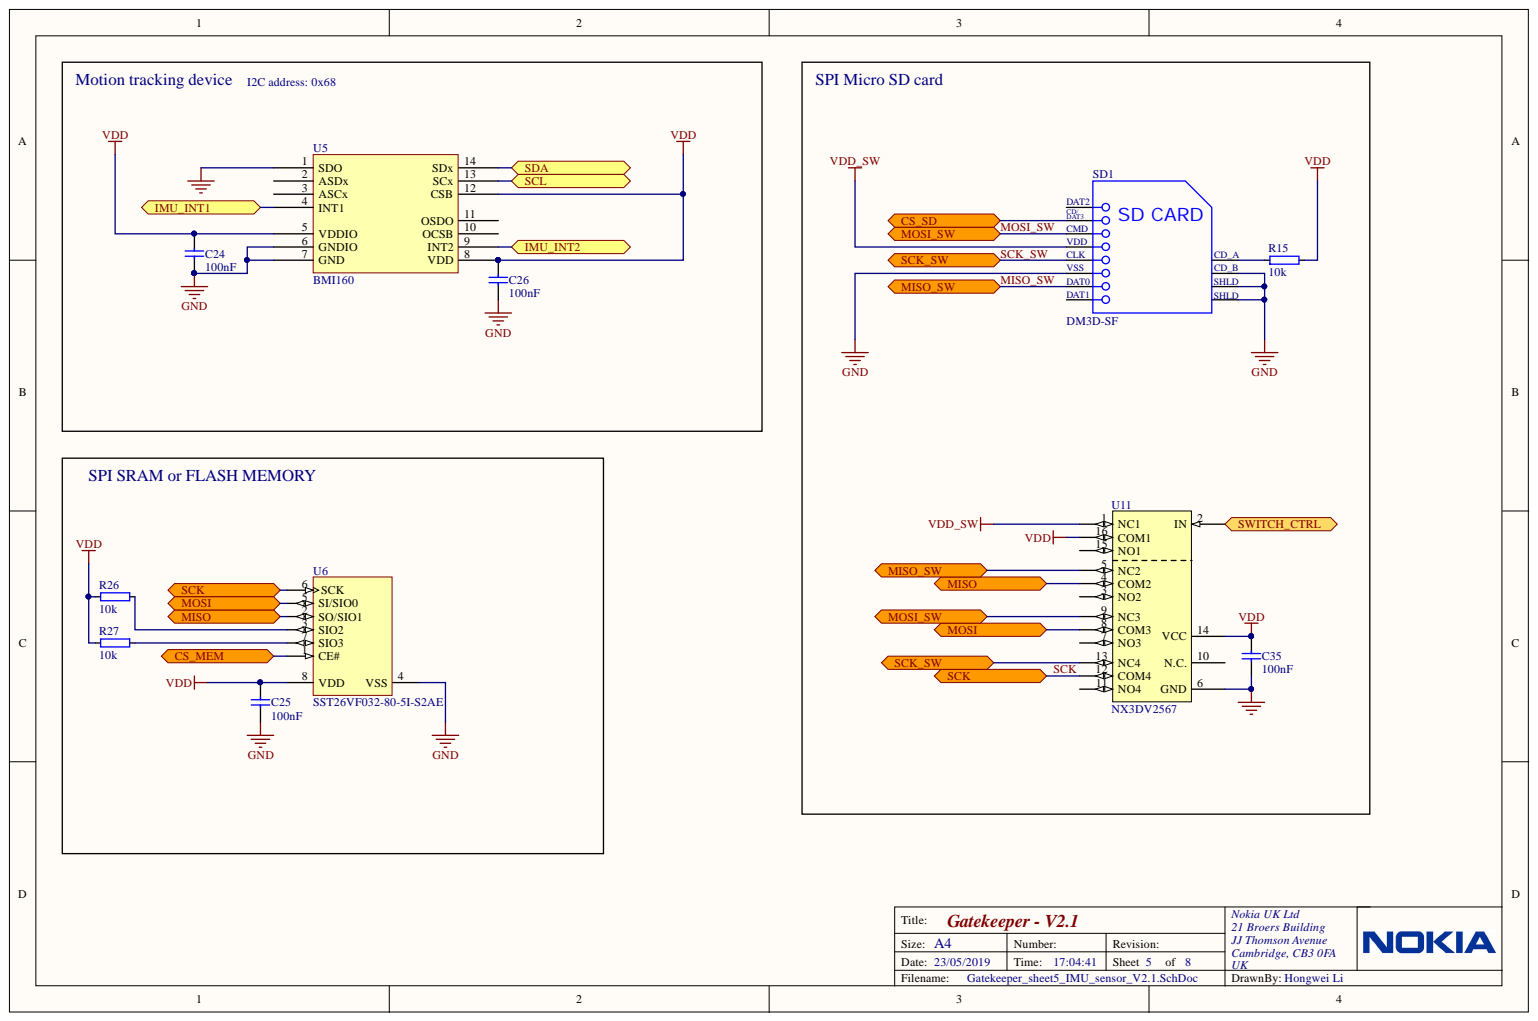
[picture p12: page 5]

Motion tracking device I2C address: 0x68

SPI Micro SD card

SPI SRAM or FLASH MEMORY

Gatekeeper - V2.1 Title: | Nokia UK Ltd 21 Broers Building JJ Thomson Avenue UK

Size: A4 | Number: | Revision:
Date: 23/05/2019 | Time: 17:04:41 | Sheet 5 of | Cambridge, CB3 0FA 8

Gatekeeper_sheet5_IMU_sensor_V2.1.SchDoc

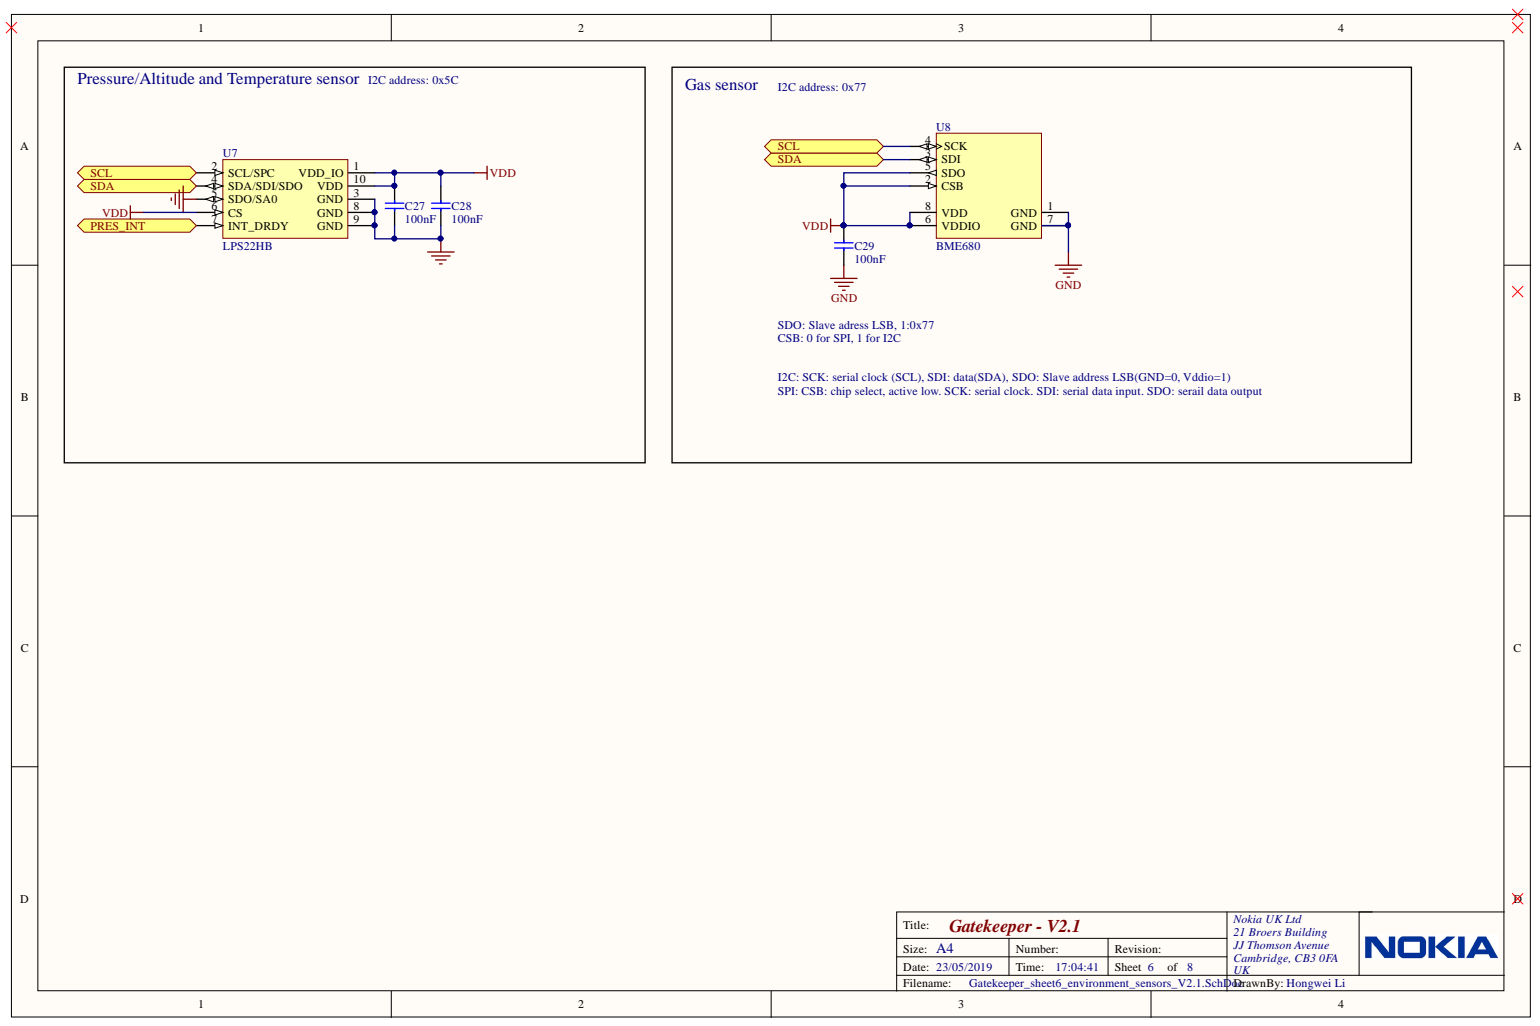
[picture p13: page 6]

CSB: 0 for SPI, 1 for I2

ock (SCL), SDI: data(SD
p select, act

ock. SDI: serial data i

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

Size: A4 | N umber: | Rev i s i o n :
Date: 2 3 / 0 5 / 2 0 1 9 | T ime: 1 7 : 0 4 : 4 1 | Sheet 6 o f 8
Fi lename: Gatekeeper_ s heet _en v iro nmen t _ sen s ors _ V 2.1.Sch | D o Draw c nBy : H o n g wei L i

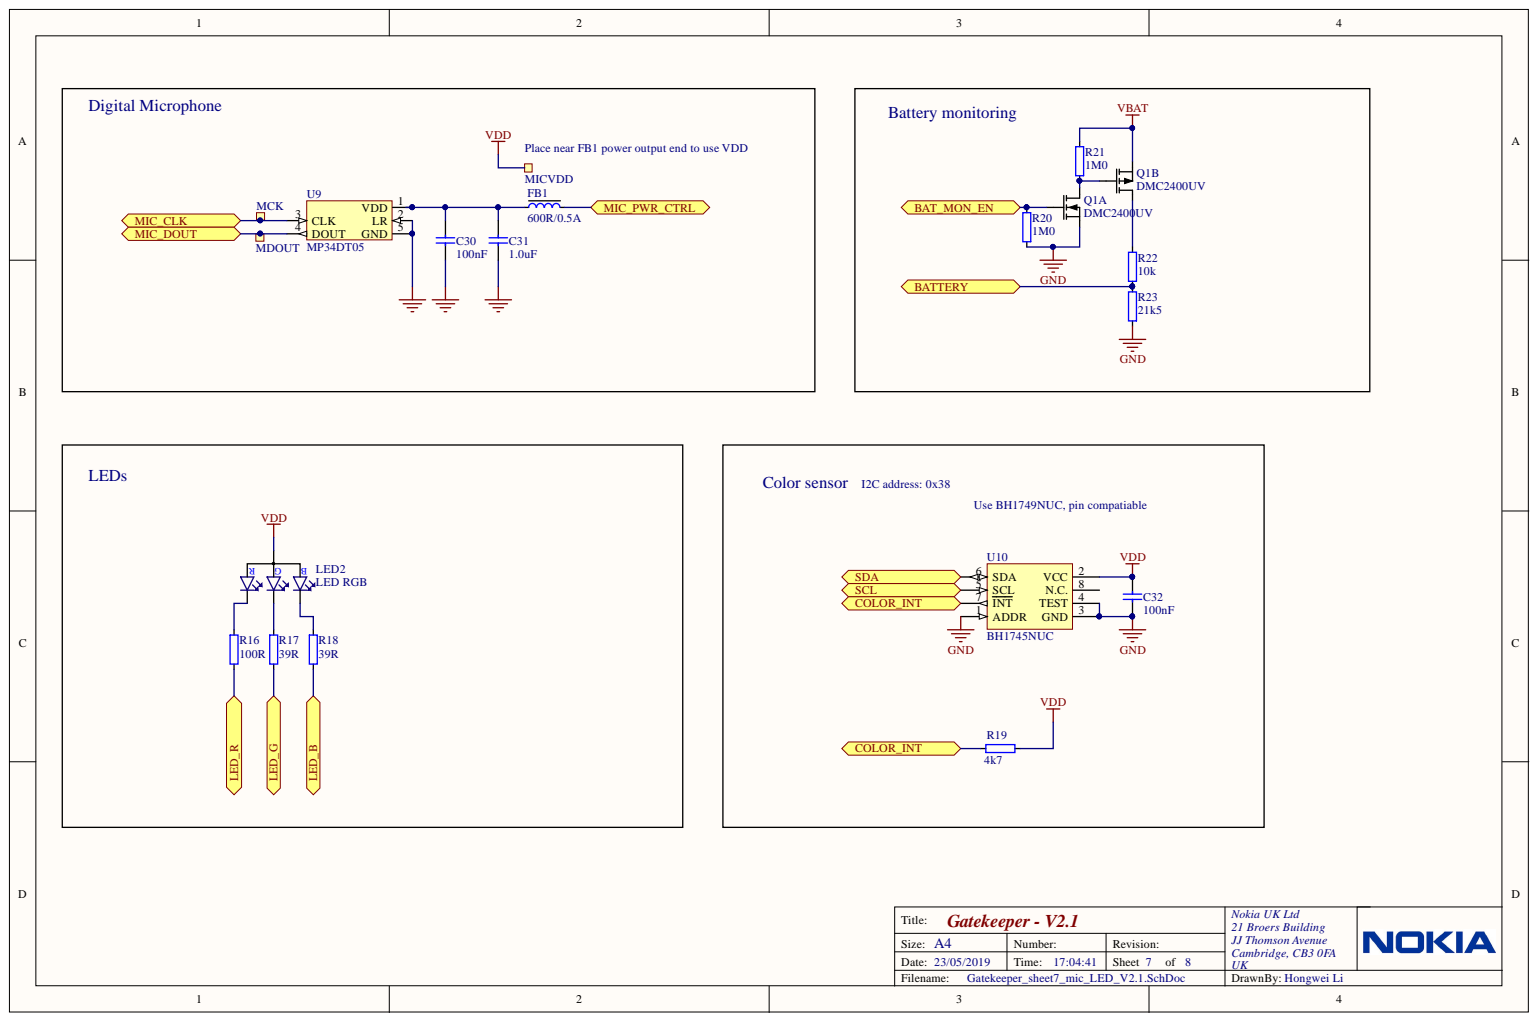
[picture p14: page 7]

Place near FB1 power output end to use VDD

Gatekeeper - V2.1 Title: | Nokia UK Ltd 21 Broers Building JJ Thomson Avenue UK

Size: A4 | Number: | Revision:
Date: 23/05/2019 | Time: 17:04:41 | Sheet 7 of | Cambridge, CB3 0FA 8

Gatekeeper_sheet7_mic_LED_V2.1.SchDoc

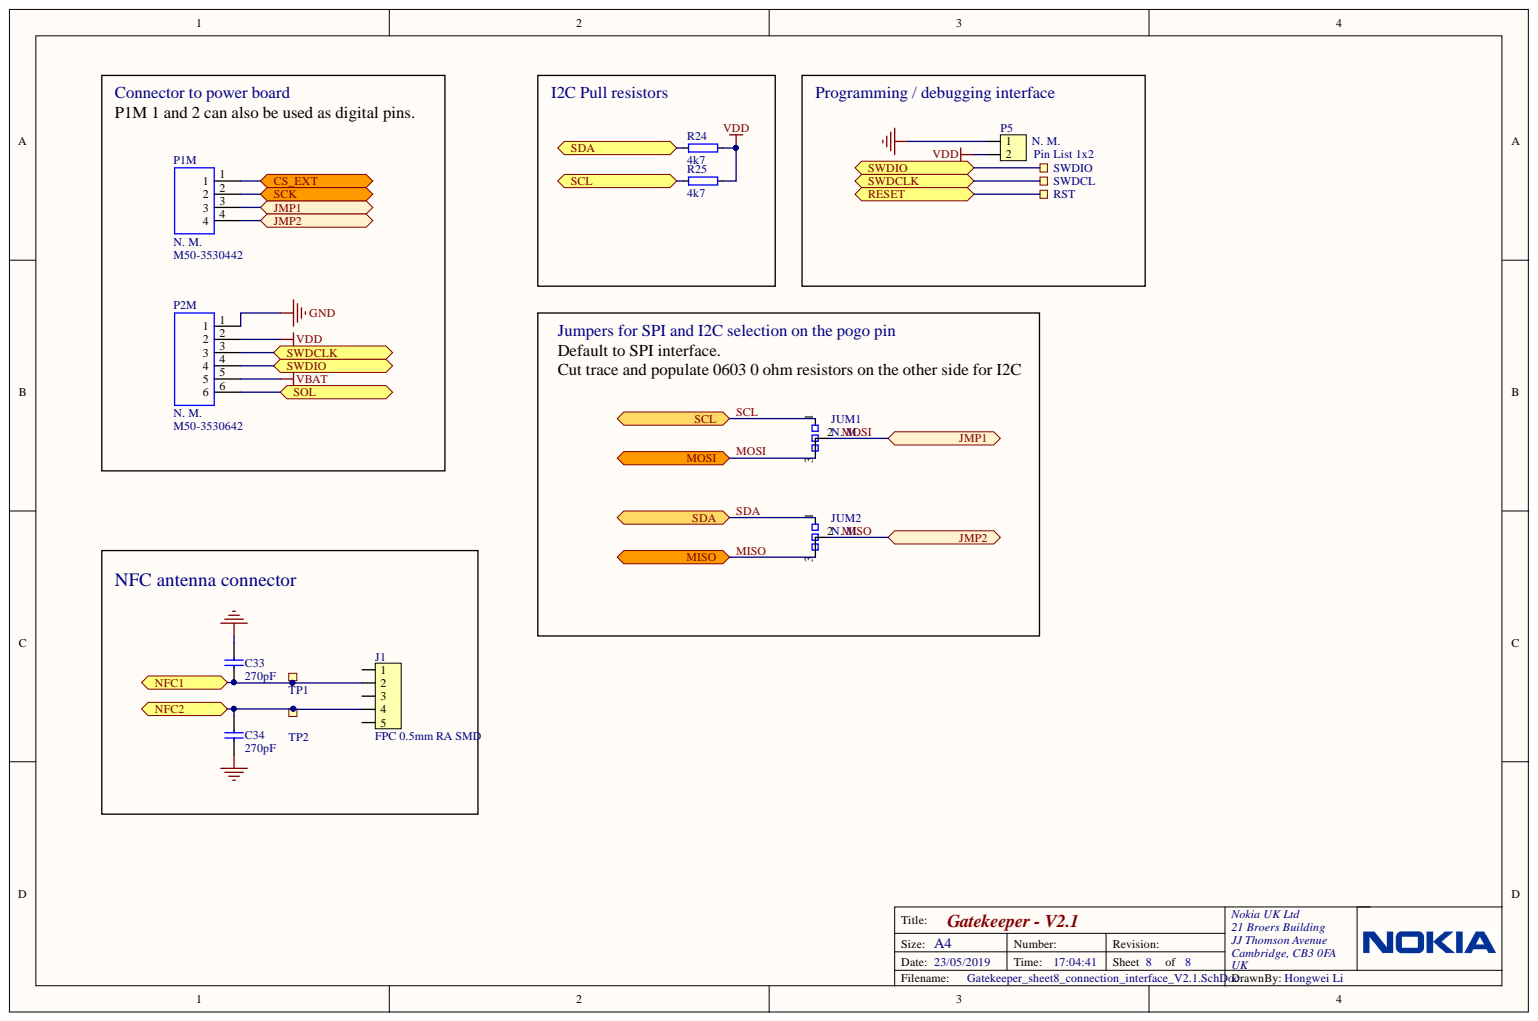
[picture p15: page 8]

Connector to power board
P1M 1 and 2 can also be used as digital pins.

Jumpers for SPI and I2C selection on the pogo pin
Default to SPI interface.
Cut trace and populate 0603 0 ohm resistors on the other side for I2C

Gatekeeper - V2.1 Title: | Nokia UK Ltd 21 Broers Building JJ Thomson Avenue UK

Size: A4 | Number: | Revision:
Date: 23/05/2019 | Time: 17:04:41 | Sheet 8 of | Cambridge, CB3 0FA 8

Gatekeeper_sheet8_connection_interface_V2.1.SchDoc

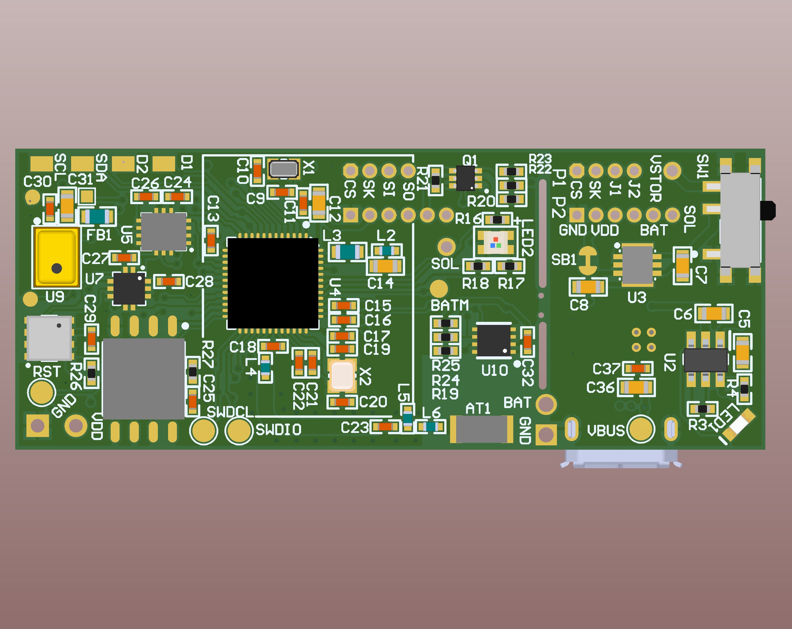
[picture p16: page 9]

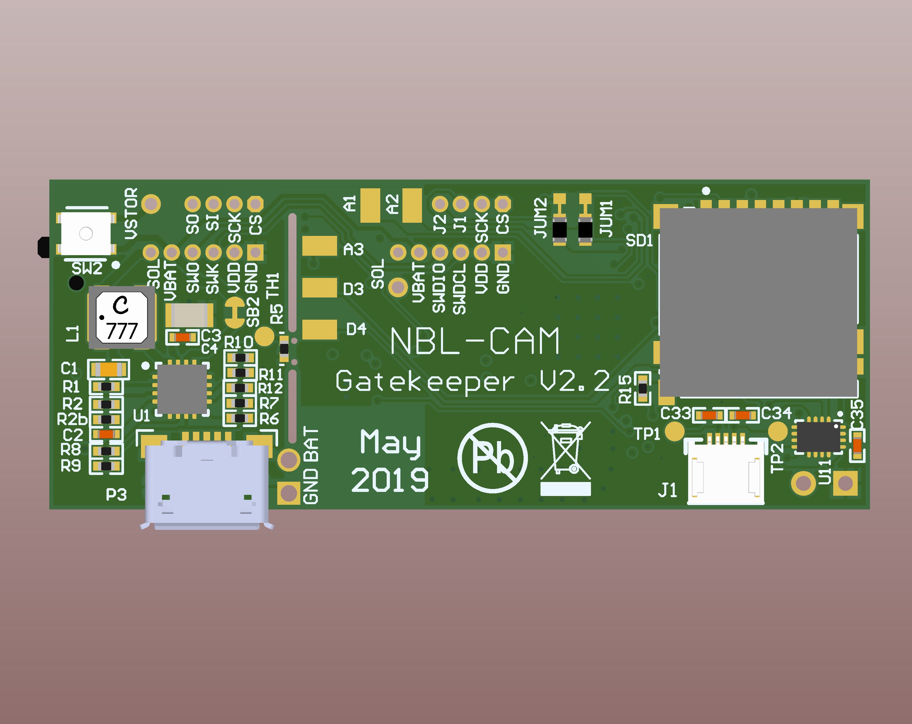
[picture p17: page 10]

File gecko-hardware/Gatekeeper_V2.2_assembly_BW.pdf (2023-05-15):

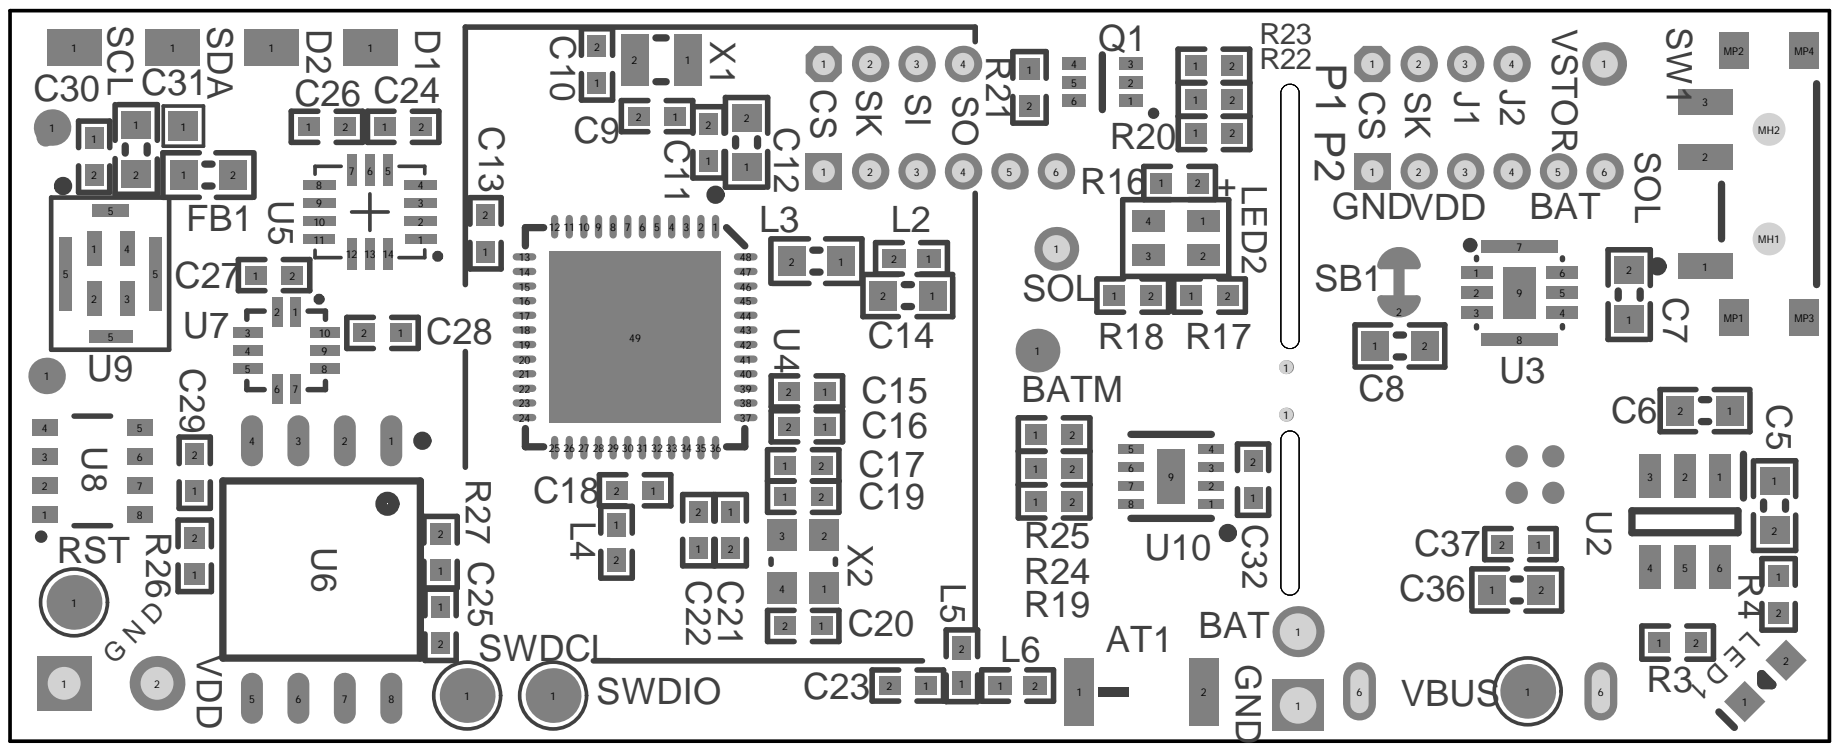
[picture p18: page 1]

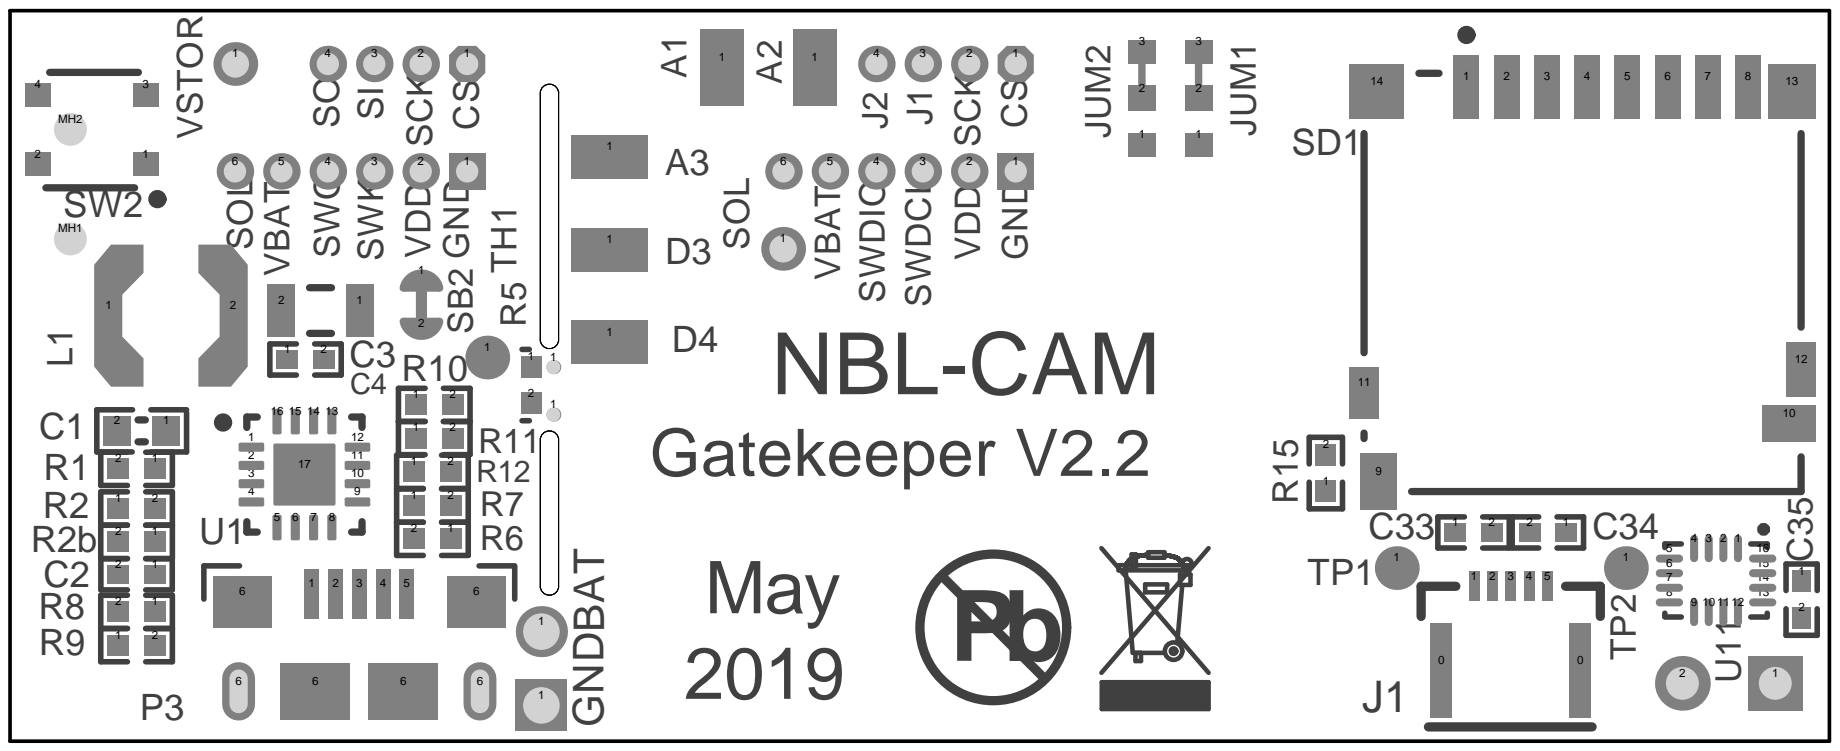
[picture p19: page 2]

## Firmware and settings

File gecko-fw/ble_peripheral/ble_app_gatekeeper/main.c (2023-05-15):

/*
 * Colyright 2018-2022 Nokia
 *
 * All software in this repository are licensed under the [BSD 3 Cluse License (BSD-3-Clause)](LICENSES\BSD-3-Clause.txt).
 * Hardware design is licensed with the [Nokia HW License](LICENSES\nokia-hw-license.txt).
 */

/** @file 
 * 
 * @defgroup ble_sdk_uart_over_ble_main main.c 
 * @{ 
 * @ingroup  ble_sdk_app_nus_eval 
 * @brief    UART over BLE application main file. 
 * 
 * This file contains the source code for a sample application that uses the Nordic UART service. 
 * This application uses the @ref srvlib_conn_params module. 
 */ 
 
#include <stdint.h> 
#include <string.h> 
#include "sdk_config.h" 
 
#include "nordic_common.h" 
#include "nrf.h" 
#include "nrfx.h" 
#include "ble_hci.h" 
#include "ble_advdata.h" 
#include "ble_advertising.h" 
#include "ble_conn_params.h" 
#include "nrf_sdh.h" 
#include "nrf_sdh_soc.h" 
#include "nrf_sdh_ble.h" 
#include "nrf_ble_gatt.h" 
#include "nrf_ble_qwr.h" 
#include "nrf_drv_wdt.h"
#include "ff.h" 
#include "diskio_blkdev.h" 
#if USE_SDCARD == 1 
#include "nrf_block_dev_sdc.h" 
#endif 
#include "nrf_drv_rtc.h" 
#include "nrf_drv_clock.h" 
#include "app_timer.h" 
#include "ble_emcd_nus.h" 
#include "app_uart.h" 
#include "app_util_platform.h" 
#include "bsp_btn_ble.h" 
#include "nrf_pwr_mgmt.h" 
#include "nrfx_pdm.h" 
#include "nrf_drv_gpiote.h"
 
 
#if defined (UART_PRESENT) 
#include "nrf_uart.h" 
#endif 
#if defined (UARTE_PRESENT) 
#include "nrf_uarte.h" 
#endif 
 
#include "nrf_log.h" 
#include "nrf_log_ctrl.h" 
#include "nrf_log_default_backends.h" 


// OTA DFU SUPPORT
#if BLE_DFU_ENABLED == 1
#include "nrf_dfu_ble_svci_bond_sharing.h"
#include "nrf_svci_async_function.h"
#include "nrf_svci_async_handler.h"
#include "ble_dfu.h"
#include "nrf_power.h"
#include "nrf_bootloader_info.h"
#endif

#include "peer_manager.h"
#include "peer_manager_handler.h"
 
#include "I2C.h"            //everything on the I2C bus 
#include "BMI160_if.h"      // Accelerometer 
#if USE_BSEC_LIBRARY == 1
#include "BSEC_if.h"        // Bosch Sensor Environmental Cluster driving BME680
#else
#include "BME680_if.h"      // Raw Environmental Sensor (Pressure, Temperature, Humidity, Gas Resistance 
#endif
#include "BH1745NUC_if.h"   // Colour Sensor 
#include "LPS22HB_if.h"     // LPS22HB Pressure / Temp 
#include "ADC.h"            // ADC for Battery Level Measurement 

// FIRMWARE VERSION information define at the beginning of sdk_config.h file
# define FIRMWARE_VERSION_ID FIRMWARE_MAJOR_VERSION * 1000000 + \
                             FIRMWARE_MINOR_VERSION *   10000 + \
                             FIRMWARE_PATCH_NUM *         100 + \
                             FIRMWARE_BUILD_NUM

// Anytime the format of the data is changed in a way that requires a change to the data  
// processing script that is NOT backward compatible with older data (i.e. not just adding  
// a new sensor) then increment this version code  
//#define CONFIG_DATA_VERSION             2 //Enable realtime set by ble master
//define  CONFIG_DATA_VERSION             3 //Increase Timestamp Bitwidth
#define CONFIG_DATA_VERSION             4  // Added Gas Quality (PPM VOC)
 
#define APP_BLE_CONN_CFG_TAG            1                                           /**< A tag identifying the SoftDevice BLE configuration. */ 
 
#if USE_BLE_COMMS == 1
#ifdef BOARD_NAME
#define DEVICE_NAME BOARD_NAME
#else
#define DEVICE_NAME                     "Gecko"                                     /**< Name of device. Will be included in the advertising data. */ 
#endif
#define NUS_SERVICE_UUID_TYPE           BLE_UUID_TYPE_VENDOR_BEGIN                  /**< UUID type for the Nordic UART Service (vendor specific). */ 
    
#define APP_BLE_OBSERVER_PRIO           3                                           /**< Application's BLE observer priority. You shouldn't need to modify this value. */ 
 
#define APP_ADV_INTERVAL                64                                          /**< The advertising interval (in units of 0.625 ms. This value corresponds to 40 ms). */ 
 
#define APP_ADV_DURATION                18000                                       /**< The advertising duration (180 seconds) in units of 10 milliseconds. */ 
 
#define MIN_CONN_INTERVAL               MSEC_TO_UNITS(20, UNIT_1_25_MS)             /**< Minimum acceptable connection interval (20 ms), Connection interval uses 1.25 ms units. */ 
#define MAX_CONN_INTERVAL               MSEC_TO_UNITS(75, UNIT_1_25_MS)             /**< Maximum acceptable connection interval (75 ms), Connection interval uses 1.25 ms units. */ 
#define SLAVE_LATENCY                   0                                           /**< Slave latency. */ 
#define CONN_SUP_TIMEOUT                MSEC_TO_UNITS(4000, UNIT_10_MS)             /**< Connection supervisory timeout (4 seconds), Supervision Timeout uses 10 ms units. */ 
#define FIRST_CONN_PARAMS_UPDATE_DELAY  APP_TIMER_TICKS(5000)                       /**< Time from initiating event (connect or start of notification) to first time sd_ble_gap_conn_param_update is called (5 seconds). */ 
#define NEXT_CONN_PARAMS_UPDATE_DELAY   APP_TIMER_TICKS(30000)                      /**< Time between each call to sd_ble_gap_conn_param_update after the first call (30 seconds). */ 
#define MAX_CONN_PARAMS_UPDATE_COUNT    3                                           /**< Number of attempts before giving up the connection parameter negotiation. */ 
#endif 

#define SEC_PARAM_BOND                  1                                           /**< Perform bonding. */
#define SEC_PARAM_MITM                  0                                           /**< Man In The Middle protection not required. */
#define SEC_PARAM_LESC                  0                                           /**< LE Secure Connections not enabled. */
#define SEC_PARAM_KEYPRESS              0                                           /**< Keypress notifications not enabled. */
#define SEC_PARAM_IO_CAPABILITIES       BLE_GAP_IO_CAPS_NONE                        /**< No I/O capabilities. */
#define SEC_PARAM_OOB                   0                                           /**< Out Of Band data not available. */
#define SEC_PARAM_MIN_KEY_SIZE          7                                           /**< Minimum encryption key size. */
#define SEC_PARAM_MAX_KEY_SIZE          16                                          /**< Maximum encryption key size. */

#define DEAD_BEEF                       0xDEADBEEF                                  /**< Value used as error code on stack dump, can be used to identify stack location on stack unwind. */ 

//#define UART_TX_BUF_SIZE                256                                         /**< UART TX buffer size. */ 
//#define UART_RX_BUF_SIZE                256                                         /**< UART RX buffer size. */ 
 
#define REFORMAT_ON_POR true  
 
#define REFORMAT_USES_DATALOG_MEM 
#define MEMORY_SIZE_KB(n) (n) * 1024 
 
#define DATALOG_MEMORY_SIZE_BYTES MEMORY_SIZE_KB(4) 
// PDM, once it has a buffer, will continue until it has filled the buffer. 
// To limit this to 500ms, the buffer needs to hold only 500ms worth of mono
// audio data at 16.125kHz i.e. 8062 samples at 16 bit/sample -> 16124 

#define AUDIO_MEMORY_SIZE_BYTES MEMORY_SIZE_KB(32) 
#define AUDIO_MEMORY_NUM_BUFFERS  2
#define AUDIO_MEMORY_BUFFER_SIZE AUDIO_MEMORY_SIZE_BYTES/AUDIO_MEMORY_NUM_BUFFERS

typedef uint8_t datalog_memory_t; 
typedef int16_t audio_memory_t;
#define SOP_BELLLABS 0x42656c6c

// BLE CONTROL COMMANDS
#define SYS_CONFIG_INFO         0x00
#define SYS_LED_ENABLE          0x01
#define IMU_SAMPLE_INTERVAL     0x02
#define ENV_SAMPLE_INTERVAL     0x03
#define COLOUR_SENSOR_INTERVAL  0x04
#define SET_TIME_COMMAND        0xff
#define AUDIO_MODE              0x05

#if USE_BLE_COMMS == 1
#if BLE_DFU_ENABLED == 1

static bool app_shutdown_handler(nrf_pwr_mgmt_evt_t event)
{
    switch (event)
    {
//        NRF_LOG_DEBUG("In app_shutdown_handler with event %d", (int) event);

        case NRF_PWR_MGMT_EVT_PREPARE_DFU:
            NRF_LOG_INFO("Power management wants to reset to DFU mode.");
            // YOUR_JOB: Get ready to reset into DFU mode
            //
            // If you aren't finished with any ongoing tasks, return "false" to
            // signal to the system that reset is impossible at this stage.
            //
            // Here is an example using a variable to delay resetting the device.
            //
            // if (!m_ready_for_reset)
            // {
            //      return false;
            // }
            // else
            //{
            //
            //    // Device ready to enter
            //    uint32_t err_code;
            //    err_code = sd_softdevice_disable();
            //    APP_ERROR_CHECK(err_code);
            //    err_code = app_timer_stop_all();
            //    APP_ERROR_CHECK(err_code);
            //}
            break;

        default:
            // YOUR_JOB: Implement any of the other events available from the power management module:
            //      -NRF_PWR_MGMT_EVT_PREPARE_SYSOFF
            //      -NRF_PWR_MGMT_EVT_PREPARE_WAKEUP
            //      -NRF_PWR_MGMT_EVT_PREPARE_RESET
            return true;
    }

    NRF_LOG_INFO("Power management allowed to reset to DFU mode.");
    return true;
}


NRF_PWR_MGMT_HANDLER_REGISTER(app_shutdown_handler, 0);

static void buttonless_dfu_sdh_state_observer(nrf_sdh_state_evt_t state, void * p_context){
  NRF_LOG_DEBUG("In buttonless_dfu_sdh_state_observer with state %d", state);
};

//NRF_SDH_STATE_OBSERVER(m_buttonless_dfu_state_obs, 0) = {};
NRF_SDH_STATE_OBSERVER(m_buttonless_dfu_state_obs, 0) = {
  .handler = buttonless_dfu_sdh_state_observer,
  .p_context = NULL,
  };


static void ble_dfu_evt_handler(ble_dfu_buttonless_evt_type_t event){
  NRF_LOG_DEBUG("In ble_dfu_evt_handler with event %d", event);
  NRF_LOG_FLUSH();
  };
#endif
#endif

// Function Declarations

void led_heartbeat_handler (void * p_context);
void config_datalogger_handler (void); 
void imu_datalogger_handler (void * p_context); 
void env_datalogger_handler (void * p_context); 
void lightsensor_datalogger_handler (void * p_context); 
void batt_level_handler (void * p_context); 
void board_led_override(void);
void board_led_restore(void);
static void nus_data_handler(ble_nus_evt_t * p_evt);
 
#if USE_SDCARD == 1 
static FRESULT sdcard_write(datalog_memory_t *, datalog_memory_t *); 
static int Open_SDCard(void); 
static int List_SDCard(); 
#endif 
 
#if USE_BLE_COMMS == 1
static uint32_t ble_send_data(datalog_memory_t *, datalog_memory_t *); 
#endif

void Swap_and_Save_Buffer(void); 

// Replace NRFX_RTC_US_TO_TICKS.  
// If us > 0x1fff then the intermediate expression overflows and truncates giving smaller  
// delays than intended.   
//#define NBL_NRFX_RTC_US_TO_TICKS(us,freq) (us > 0x1fff) ? (us / 1000000) * freq : (((us) * (freq)) / 1000000U) 
 
#define NBL_NRFX_RTC_US_TO_TICKS(us, freq) (int32_t) ((us / 1000000.0) * freq) 
 
#define FILENAME_BASENAME "dlog_" 
#define FILENAME_SUFFIX "bin" 
#define MAX_FILESIZE_4GB 0xffffffff /* Corresponds to 4GB-1 */ 
#define MAX_FILESIZE_2GB 0x80000000 /* Corresponds to 2GB   */ 
#define MAX_FILESIZE MAX_FILESIZE_2GB 
 
#ifndef BOARD_CUSTOM 
#  define SDC_SCK_PIN     SPIM0_SCK_PIN   ///< SDC serial clock (SCK) pin. 
#  define SDC_MOSI_PIN    SPIM0_MOSI_PIN  ///< SDC serial data in (DI) pin. 
#  define SDC_MISO_PIN    SPIM0_MISO_PIN  ///< SDC serial data out (DO) pin. 
#  define SDC_CS_PIN      SPIM0_SS_PIN    ///< SDC chip select (CS) pin. 
#endif 
 
//Time (in miliseconds) between LED Flashes 
#define PULSE_LED_PERIOD_MS 10000     
//Duration (in miliseconds) of LED Flashes 
#define PULSE_LED_ON_TIME_MS 50  
#define PULSE_LED_OFF_TIME_MS (PULSE_LED_PERIOD_MS - PULSE_LED_ON_TIME_MS) 
 
#define DEFAULT_IMU_SENSOR_SAMPLE_PERIOD_MS 50  
#define DEFAULT_ENV_SENSOR_SAMPLE_PERIOD_MS 30000 
#define DEFAULT_COLOUR_SENSOR_SAMPLE_PERIOD_MS 300 
#define DEFAULT_BATTERY_LEVEL_SAMPLE_PERIOD_MS 30000
 
//#if BOARD_HAS_PDM_MIC == 1 
#define DEFAULT_AUDIO_SAMPLE_PERIOD_MS 1000 
#define DEFAULT_AUDIO_SAMPLE_SIZE_MS 500
//#endif // BOARD_HAS_PDM_MIC 

typedef struct packet_info_struct { 
    uint32_t  sop; 
    uint32_t  timestamp_hi; // If we represent this as 64-bit we have alignment issues with padding added
    uint32_t  timestamp_lo; // So send as two 32-bit numbers and put together in the app. 
    uint8_t   logger_id; 
    uint8_t   length; 
    uint16_t  custom;     // Makes the structure end 32-bit aligned.
} packet_info_t; 
 
 
#if GATEKEEPER_BUFFER_SENSOR_DATA==1 
static datalog_memory_t datalog_memory_0 [DATALOG_MEMORY_SIZE_BYTES/sizeof(datalog_memory_t)]; 
static datalog_memory_t datalog_memory_1 [DATALOG_MEMORY_SIZE_BYTES/sizeof(datalog_memory_t)]; 
 
static datalog_memory_t *m_p_datalog_mem; 
static uint16_t m_write_offset; 
#endif  //GATEKEEPER_BUFFER_SENSOR_DATA
 
#if BOARD_HAS_PDM_MIC == 1   
static audio_memory_t   audiodata_memory[AUDIO_MEMORY_NUM_BUFFERS] [AUDIO_MEMORY_BUFFER_SIZE/sizeof(audio_memory_t)]; 
#endif // BOARD_HAS_PDM_MIC 

uint16_t m_imu_sensor_sample_period_ms = DEFAULT_IMU_SENSOR_SAMPLE_PERIOD_MS;
uint16_t m_env_sensor_sample_period_ms = DEFAULT_ENV_SENSOR_SAMPLE_PERIOD_MS;
uint16_t m_colour_sensor_sample_period_ms = DEFAULT_COLOUR_SENSOR_SAMPLE_PERIOD_MS;
uint16_t m_audio_sample_period_ms = DEFAULT_AUDIO_SAMPLE_PERIOD_MS;
uint16_t m_audio_sample_size_ms = DEFAULT_AUDIO_SAMPLE_SIZE_MS;

// Variable to indicate if watchdog is running
uint8_t m_watchdog_running = 0;

// Variable to determine name of files written to SDCard
uint16_t m_fileindex = 0; 
 

// Variable to store reason for last reset
uint32_t m_last_reset_reason;

enum reset_type { PowerOnReset=0, 
                  ResetPin=1, 
                  WatchdogReset=2,
                  SoftwareReset=4,
                  CPULockupReset=8, 
                  GPIOWakeUp=0x10000, 
                  LPCompWakeUp=0x20000, 
                  DebugWakeUp=0x40000, 
                  NFCWakeUp=0x80000
                  };;
 
/**< Get Compare event COMPARE_TIME seconds after the counter starts from 0. */ 
#define COMPARE_COUNTERTIME  (30UL)  
#define RTC_CONFIG_PRESCALER 0 
 
#ifndef BOARD_CUSTOM 
// Define any leds as we don't know what colour they are. 
// These are already defined for BOARD_CUSTOM. 
#define LED_GREEN      0 
#define LED_BLUE       1 
#define LED_RED        2 
#endif 
 
#if USE_BLE_COMMS == 1
BLE_NUS_DEF(m_nus, NRF_SDH_BLE_TOTAL_LINK_COUNT);                                   /**< BLE NUS service instance. */ 
NRF_BLE_GATT_DEF(m_gatt);                                                           /**< GATT module instance. */ 
NRF_BLE_QWR_DEF(m_qwr);                                                             /**< Context for the Queued Write module.*/ 
BLE_ADVERTISING_DEF(m_advertising);                                                 /**< Advertising module instance. */ 
 
uint8_t   m_ble_wait_for_tx = 0; 

static uint16_t   m_conn_handle          = BLE_CONN_HANDLE_INVALID;                 /**< Handle of the current connection. */ 
static uint16_t   m_ble_nus_max_data_len = BLE_GATT_ATT_MTU_DEFAULT - 3;            /**< Maximum length of data (in bytes) that can be transmitted to the peer by the Nordic UART service module. */ 
static ble_uuid_t m_adv_uuids[]          =                                          /**< Universally unique service identifier. */ 
{ 
    {BLE_UUID_NUS_SERVICE, NUS_SERVICE_UUID_TYPE}/*,
    {BLE_UUID_BATTERY_SERVICE, BLE_UUID_TYPE_BLE},
    {BLE_UUID_BLOOD_PRESSURE_SERVICE, BLE_UUID_TYPE_BLE},
    {BLE_UUID_ALERT_NOTIFICATION_SERVICE, BLE_UUID_TYPE_BLE}*/
}; 
#endif  //USE_BLE_COMMS

uint8_t   m_ble_connected = 0; 
uint16_t  m_rtc2_cc2_count = 0; 
uint8_t   m_adc_oversample; 
uint8_t   m_lps22hb_present = 1; 
 

/**@brief Function for assert macro callback. 
 * 
 * @details This function will be called in case of an assert in the SoftDevice. 
 * 
 * @warning This handler is an example only and does not fit a final product. You need to analyse 
 *          how your product is supposed to react in case of Assert. 
 * @warning On assert from the SoftDevice, the system can only recover on reset. 
 * 
 * @param[in] line_num    Line number of the failing ASSERT call. 
 * @param[in] p_file_name File name of the failing ASSERT call. 
 */ 
void assert_nrf_callback(uint16_t line_num, const uint8_t * p_file_name) 
{ 
    NRF_LOG_ERROR("ASSERTION ERROR %s:%d", p_file_name, line_num);
    app_error_handler(DEAD_BEEF, line_num, p_file_name); 
} 
 
/**@brief Function for SystemView Timestamp Retrieval. 
 * 
*/ 
 
#if DEBUG_WITH_SYSTEMVIEW == 1
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
int main(void) 
{ 
  bool erase_bonds; 
  ret_code_t err_code; 
 
#if DEBUG_WITH_SYSTEMVIEW == 1  
  SEGGER_SYSVIEW_Conf();            /* Configure and initialize SystemView  */ 
  SEGGER_SYSVIEW_Start();           /* Starts SystemView recording*/ 
  SEGGER_SYSVIEW_OnIdle();          /* Tells SystemView that System is currently in "Idle"*/ 
#endif 

  // Read and store the reset reason
  m_last_reset_reason = NRF_POWER->RESETREAS;

  // Reset the reset reason (could also write 0xf)
  NRF_POWER->RESETREAS = m_last_reset_reason;

  // Clear the timestamp.
  set_ts64(&m_timestamp_offset, 0);
  set_ts64(&m_old_timestamp_offset, 0);

  // Indicate that the watchdog is not yet running
  m_watchdog_running = 0;

#if USE_BLE_COMMS == 0
  // If BLE_COMMS not used then we need to start the LF Clock.
  lfclk_config(); 
#endif

  // Initialize. 
  log_init();

#if BLE_DFU_ENABLED==1 
  // Initialize the async SVCI interface to bootloader before any interrupts are enabled.
  err_code = ble_dfu_buttonless_async_svci_init();
  APP_ERROR_CHECK(err_code);
#endif


  app_timers_init();
  buttons_leds_init(&erase_bonds); 
  power_management_init(); 

#if NBL_LOG_BOOT == 1
  char reason_string [55];
  resetreas2string(m_last_reset_reason, reason_string);
  NRF_LOG_DEBUG("");
  NRF_LOG_DEBUG("");
  NRF_LOG_DEBUG("");
  NRF_LOG_DEBUG("*****************************************");
  NRF_LOG_DEBUG("Booting.");
  NRF_LOG_DEBUG("--> Last reset was %s", reason_string);
  NRF_LOG_DEBUG("*****************************************");
  NRF_LOG_FLUSH();
#endif

#if BLE_DFU_ENABLED==1 
  NRF_LOG_DEBUG("Secure DFU Enabled!!!");
  NRF_LOG_FLUSH();
#else
  NRF_LOG_DEBUG("Secure NOT Enabled!!!");
  NRF_LOG_FLUSH();
#endif

#if USE_BLE_COMMS == 1
  NRF_LOG_DEBUG("ble_stack_init...");
  NRF_LOG_FLUSH();  
  ble_stack_init();  
  peer_manager_init();  
  gap_params_init(); 
  gatt_init(); 
  services_init(); 
  advertising_init(); 
  conn_params_init(); 
#endif

#if BLE_DFU_ENABLED==1 
  NRF_LOG_DEBUG("BLE Comms Setup Complete...");
  NRF_LOG_FLUSH();
#endif

  //I2C bus  
  I2C_init(); 

   
#if USE_SDCARD == 1 
  
  // Turn the SD Card on by setting SWITCH_CTRL low
  // Set the SWITCH_CTRL pin to output 
  nrf_gpio_cfg_output(SWITCH_CTRL); 
   
  // Power cycle the SD Card. SWITCH_CTRL high disables power.
  nrf_gpio_pin_set(SWITCH_CTRL);
  nrf_delay_ms(100);

  // Drive the SWITCH_CTRL low to enable power
  nrf_gpio_pin_clear(SWITCH_CTRL);


#ifdef DEBUG 
  // Use LEDs to indicate progress. 
  board_led_on(LED_BLUE); 
  board_led_on(LED_RED); 
#endif 
 
  // Open the SDCard. 
  // Check that the card is there and readable 
  err_code = Open_SDCard(); 
  if (err_code) { 
    //error_led_flash_loop(); 
    error_led_flash_5s();
  } 
 
  err_code = List_SDCard(); 
 
  if (err_code) { 
    //error_led_flash_loop(); 
       error_led_flash_5s();

  } 
#endif 
   

// RTC2 (timestamp) configuration 
rtc_config(); 


#if USE_DUMMY_SENSORS == 0 

  //BMI160 IMU 
#if BOARD_HAS_BMI160 == 1
  BMI160_Turn_On(); 

  // If using BLE, use INT1 interrupt to restart advertising
  // If using SDCard, use INT1 to force datapurge to SDCard.

  // Enable INT1 as interrupt using GPIOTE
  err_code = nrf_drv_gpiote_init();
  APP_ERROR_CHECK(err_code);
  nrf_drv_gpiote_in_config_t in_config = GPIOTE_CONFIG_IN_SENSE_TOGGLE(true);
  err_code = nrf_drv_gpiote_in_init(IMU_INT1, &in_config, imu_int1_handler);
  APP_ERROR_CHECK(err_code);
  nrf_drv_gpiote_in_event_enable(IMU_INT1, true);
  nrf_delay_ms(50); 
#endif


//BME680 Pressure Temperature Humidity and Gas Sensor  
#if BOARD_HAS_BME680 == 1

#if USE_BSEC_LIBRARY==1
      BSEC_Configure_and_Run(&bsec_callback);
#else
  BME680_Turn_On(); 
  nrf_delay_ms(50); 
#endif
#endif
 
  //BH1745NUC Colour Light Sensor 
#if BOARD_HAS_BH1745NUC == 1
  BH1745NUC_Turn_On(); 
  nrf_delay_ms(50); 
#endif

 
  // LPS22HB Pressure/Temp 
#if BOARD_HAS_LPS22HB == 1
  if ((NRF_UICR->CUSTOMER[0] & 0x2) == 0) { 
    m_lps22hb_present = 0; 
  } else { 
    LPS22HB_Turn_On(); 
  } 
#endif

#if BOARD_HAS_BATMON == 1
  //ADC subsystem for battery read
  nrf_gpio_cfg_output(BAT_MON_EN); 
  ADC_init_with_callback(&batt_level_updated_callback); 
#endif
 
#endif 
 
#if GATEKEEPER_BUFFER_SENSOR_DATA==1 
  // Point to first buffer for datalog memory and reset write offset 
  m_p_datalog_mem     = (datalog_memory_t*) datalog_memory_0; 
  m_write_offset      = 0; 
#endif 
 
  m_ble_connected = 0; 
 
  // Make sure the LEDs are off. 
  board_led_off(LED_BLUE); 
  board_led_off(LED_RED); 
  board_led_off(LED_GREEN); 
 
#if USE_SDCARD == 1 
  // Write configuration information 
  // (Although BLE not connected - it puts this as the first bit of information in the SDCard  
  // datalog. 
  config_datalogger_handler(); 
#endif 
 
#if BOARD_HAS_PDM_MIC == 1   
  // Configure PDM for Audio Capture 
  pdm_init(); 
#endif // BOARD_HAS_PDM_MIC 
 
  // app_timer configuration 
  app_timer_config();

#if BOARD_HAS_PDM_MIC == 1   
  // Start PDM for Audio Capture 
  pdm_start();
#endif // BOARD_HAS_PDM_MIC

  // Start the Watchdog Timer
  watchdog_init();
 
#if USE_BLE_COMMS == 1
  // Start execution. 
  NRF_LOG_INFO("Starting BLE..."); 
 
  advertising_start(); 
#endif
  // Enter main loop. 
  for (;;) 
  { 
      idle_state_handle(); // Calls sd_app_evt_wait(); 
  } 
} 
 
 
/** 
 * @} 
 */ 

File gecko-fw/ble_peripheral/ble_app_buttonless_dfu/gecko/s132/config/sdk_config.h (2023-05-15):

/**
 * Copyright (c) 2017 - 2019, Nordic Semiconductor ASA
 *
 * All rights reserved.
 *
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
 * 3. Neither the name of Nordic Semiconductor ASA nor the names of its
 *    contributors may be used to endorse or promote products derived from this
 *    software without specific prior written permission.
 *
 * 4. This software, with or without modification, must only be used with a
 *    Nordic Semiconductor ASA integrated circuit.
 *
 * 5. Any software provided in binary form under this license must not be reverse
 *    engineered, decompiled, modified and/or disassembled.
 *
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
 */


 
#ifndef RETARGET_ENABLED
#define RETARGET_ENABLED 1
#endif 

#ifndef SDK_CONFIG_H
#define SDK_CONFIG_H
// <<< Use Configuration Wizard in Context Menu >>>\n
#ifdef USE_APP_CONFIG
#include "app_config.h"
#endif
// <h> Board Support 

//==========================================================
// <q> BSP_BTN_BLE_ENABLED  - bsp_btn_ble - Button Control for BLE
 

#ifndef BSP_BTN_BLE_ENABLED
#define BSP_BTN_BLE_ENABLED 1
#endif

// </h> 
//==========================================================

// <h> nRF_BLE 

//==========================================================
// <q> BLE_ADVERTISING_ENABLED  - ble_advertising - Advertising module
 

#ifndef BLE_ADVERTISING_ENABLED
#define BLE_ADVERTISING_ENABLED 1
#endif

// <e> NRF_BLE_CONN_PARAMS_ENABLED - ble_conn_params - Initiating and executing a connection parameters negotiation procedure
//==========================================================
#ifndef NRF_BLE_CONN_PARAMS_ENABLED
#define NRF_BLE_CONN_PARAMS_ENABLED 1
#endif
// <o> NRF_BLE_CONN_PARAMS_MAX_SLAVE_LATENCY_DEVIATION - The largest acceptable deviation in slave latency. 
// <i> The largest deviation (+ or -) from the requested slave latency that will not be renegotiated.

#ifndef NRF_BLE_CONN_PARAMS_MAX_SLAVE_LATENCY_DEVIATION
#define NRF_BLE_CONN_PARAMS_MAX_SLAVE_LATENCY_DEVIATION 499
#endif

// <o> NRF_BLE_CONN_PARAMS_MAX_SUPERVISION_TIMEOUT_DEVIATION - The largest acceptable deviation (in 10 ms units) in supervision timeout. 
// <i> The largest deviation (+ or -, in 10 ms units) from the requested supervision timeout that will not be renegotiated.

#ifndef NRF_BLE_CONN_PARAMS_MAX_SUPERVISION_TIMEOUT_DEVIATION
#define NRF_BLE_CONN_PARAMS_MAX_SUPERVISION_TIMEOUT_DEVIATION 65535
#endif

// </e>

// <q> NRF_BLE_GATT_ENABLED  - nrf_ble_gatt - GATT module
 

#ifndef NRF_BLE_GATT_ENABLED
#define NRF_BLE_GATT_ENABLED 1
#endif

// <e> NRF_BLE_QWR_ENABLED - nrf_ble_qwr - Queued writes support module (prepare/execute write)
//==========================================================
#ifndef NRF_BLE_QWR_ENABLED
#define NRF_BLE_QWR_ENABLED 1
#endif
// <o> NRF_BLE_QWR_MAX_ATTR - Maximum number of attribute handles that can be registered. This number must be adjusted according to the number of attributes for which Queued Writes will be enabled. If it is zero, the module will reject all Queued Write requests. 
#ifndef NRF_BLE_QWR_MAX_ATTR
#define NRF_BLE_QWR_MAX_ATTR 0
#endif

// </e>

// <e> PEER_MANAGER_ENABLED - peer_manager - Peer Manager
//==========================================================
#ifndef PEER_MANAGER_ENABLED
#define PEER_MANAGER_ENABLED 1
#endif
// <o> PM_MAX_REGISTRANTS - Number of event handlers that can be registered. 
#ifndef PM_MAX_REGISTRANTS
#define PM_MAX_REGISTRANTS 3
#endif

// <o> PM_FLASH_BUFFERS - Number of internal buffers for flash operations. 
// <i> Decrease this value to lower RAM usage.

#ifndef PM_FLASH_BUFFERS
#define PM_FLASH_BUFFERS 4
#endif

// <q> PM_CENTRAL_ENABLED  - Enable/disable central-specific Peer Manager functionality.
 

// <i> Enable/disable central-specific Peer Manager functionality.

#ifndef PM_CENTRAL_ENABLED
#define PM_CENTRAL_ENABLED 0
#endif

// <q> PM_SERVICE_CHANGED_ENABLED  - Enable/disable the service changed management for GATT server in Peer Manager.
 

// <i> If not using a GATT server, or using a server wihout a service changed characteristic,
// <i> disable this to save code space.

#ifndef PM_SERVICE_CHANGED_ENABLED
#define PM_SERVICE_CHANGED_ENABLED 1
#endif

// <q> PM_PEER_RANKS_ENABLED  - Enable/disable the peer rank management in Peer Manager.
 

// <i> Set this to false to save code space if not using the peer rank API.

#ifndef PM_PEER_RANKS_ENABLED
#define PM_PEER_RANKS_ENABLED 1
#endif

// <q> PM_LESC_ENABLED  - Enable/disable LESC support in Peer Manager.
 

// <i> If set to true, you need to call nrf_ble_lesc_request_handler() in the main loop to respond to LESC-related BLE events. If LESC support is not required, set this to false to save code space.

#ifndef PM_LESC_ENABLED
#define PM_LESC_ENABLED 0
#endif
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

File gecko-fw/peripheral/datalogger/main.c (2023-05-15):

/**
 * Copyright (c) 2016 - 2018, Nordic Semiconductor ASA
 *
 * All rights reserved.
 *
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
 * 3. Neither the name of Nordic Semiconductor ASA nor the names of its
 *    contributors may be used to endorse or promote products derived from this
 *    software without specific prior written permission.
 *
 * 4. This software, with or without modification, must only be used with a
 *    Nordic Semiconductor ASA integrated circuit.
 *
 * 5. Any software provided in binary form under this license must not be reverse
 *    engineered, decompiled, modified and/or disassembled.
 *
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
 */
/** @file
 * @defgroup datalogger main.c
 * @{
 * @ingroup datalogger
 * @brief EMCD Datalogger main file.
 *
 * This file contains the source code for the EMCD Datalogger using FAT filesystem and SD card library.
 *
 */
#include "nrf.h"
#include "bsp.h"
#include "ff.h"
#include "diskio_blkdev.h"
#include "nrf_block_dev_sdc.h"
#include "nrf_drv_rtc.h"
#include "nrf_drv_clock.h"
#include "nrfx_pdm.h"

//#include "nrf_drv_timer.h"
#include "nrf_log.h"
#include "nrf_delay.h"
#include "nrf_log_ctrl.h"
#include "nrf_log_default_backends.h"

#include "I2C.h"            //everything on the I2C bus
#include "BMI160_if.h"      // Accelerometer
#include "BME680_if.h"      // Environmental (Pressure, Temperature, Humidity, Gas (VOC)
#include "BH1745NUC_if.h"   // Colour Sensor
#include "LPS22HB_if.h"     // LPS22HB Pressure / Temp
#include "ADC.h"            // ADC for Battery Level Measurement

// Anytime the format of the data is changed in a way that requires a change to the data 
// processing script that is NOT backward compatible with older data (i.e. not just adding 
// a new sensor) then increment this version code 

#define CONFIG_DATA_VERSION 1
#define REFORMAT_ON_START true 

#define REFORMAT_USES_DATALOG_MEM

#define MEMORY_SIZE_KB(n) (n) * 1024

#define DATALOG_MEMORY_SIZE_BYTES MEMORY_SIZE_KB(21)
#define AUDIO_MEMORY_SIZE_BYTES MEMORY_SIZE_KB(1)

// Swap buffers when 90% full
#define DATALOG_MEMORY_LIMIT DATALOG_MEMORY_SIZE_BYTES * 10 / 9 

// Replace NRFX_RTC_US_TO_TICKS. 
// If us > 0x1fff then the intermediate expression overflows and truncates giving smaller 
// delays than intended.  
//#define NBL_NRFX_RTC_US_TO_TICKS(us,freq) (us > 0x1fff) ? (us / 1000000) * freq : (((us) * (freq)) / 1000000U)

#define NBL_NRFX_RTC_US_TO_TICKS(us, freq) (int32_t) ((us / 1000000.0) * freq)


#define FILENAME_BASENAME "dlog"
#define FILENAME_SUFFIX "bin"
#define MAX_FILESIZE_4GB 0xffffffff /* Corresponds to 4GB-1 */
#define MAX_FILESIZE_2GB 0x80000000 /* Corresponds to 2GB   */
#define MAX_FILESIZE MAX_FILESIZE_2GB

#define SDC_SCK_PIN     SPI_SCK   ///< SDC serial clock (SCK) pin.
#define SDC_MOSI_PIN    SPI_MOSI  ///< SDC serial data in (DI) pin.
#define SDC_MISO_PIN    SPI_MISO  ///< SDC serial data out (DO) pin.
#define SDC_CS_PIN      CS_SD     ///< SDC chip select (CS) pin.

//Time (in miliseconds) between LED Flashes
#define PULSE_LED_PERIOD_MS 10000    
//Duration (in miliseconds) of LED Flashes
#define PULSE_LED_ON_TIME_MS 50 

#define PULSE_LED_OFF_TIME_MS (PULSE_LED_PERIOD_MS - PULSE_LED_ON_TIME_MS)

#define IMU_SENSOR_SAMPLE_PERIOD_MS 50
#define ENV_SENSOR_SAMPLE_PERIOD_MS 1000
#define COLOUR_SENSOR_SAMPLE_PERIOD_MS 500
#if CAPTURE_AUDIO == 1
#define AUDIO_SAMPLE_PERIOD_MS 5000
#define AUDIO_SAMPLE_SIZE_MS 500
#endif // CAPTURE_AUDIO

/**< Get Compare event COMPARE_TIME seconds after the counter starts from 0. */
#define COMPARE_COUNTERTIME  (30UL) 
#define RTC_CONFIG_PRESCALER 0

#ifndef BOARD_CUSTOM
// Define any leds as we don't know what colour they are.
// These are already defined for BOARD_CUSTOM.
#define LED_GREEN      0
#define LED_BLUE       1
#define LED_RED        2
#endif

///
/// EMCD Cambridge Data Logger
///
/// Data logger(s) run on timers, updating a RAM array with the aquired data.
/// 
/// SD Card Writes also run on a timer, and/or when the RAM array is getting full.
/// 
/// Each logger uses has different data lengths for entries used, so logger/reader 
/// has to be able to cope with that.
///
/// Each entry has MagicNumber, timestamp, logger_id, entry_size, log_data[entry_size].
/// Looks like size of packet_info_t is expanded to be word aligned so could put 
/// more information in here.
/// 
/// Memory is organised as uint8_t for easier file writing (and Radio Communication)
/// so logger is responsible for this conversion. 
/// 
/// NOTE: 
///    Not using malloc or nrf_malloc here as the extra code required to support this 
///    takes up so much RAM - better to use that memory by declaring an array here. 

typedef uint8_t datalog_memory_t ;
typedef uint16_t audio_memory_t ;

#define SOP_BELLLABS 0x42656c6c

typedef struct {
    uint32_t  sop;
    uint32_t  timestamp;  // Gives 36 hours at 32.768KHz. Need 64 bit for more.
    uint8_t   logger_id;
    uint8_t   length;
    uint16_t  custom;     // Makes the structure end 32-bit aligned.
} packet_info_t;


static datalog_memory_t datalog_memory_0 [DATALOG_MEMORY_SIZE_BYTES/sizeof(datalog_memory_t)];
static datalog_memory_t datalog_memory_1 [DATALOG_MEMORY_SIZE_BYTES/sizeof(datalog_memory_t)];
#if CAPTURE_AUDIO == 1  
static audio_memory_t   audiodata_memory [AUDIO_MEMORY_SIZE_BYTES/sizeof(audio_memory_t)];
#endif // CAPTURE_AUDIO
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
